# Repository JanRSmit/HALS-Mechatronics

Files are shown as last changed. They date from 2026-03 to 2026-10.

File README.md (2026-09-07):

# HALS-Mechatronics design

Note: see update status and end of this README.

THE HALS (Holographic Acoustic Loudspeaker Scanner) Mechatronics design process documentation and 3D models. 
Unlike code a physical device cannot be copied. So instead in this repository covers the design, construction, alignment and test process i followed. In this way it provides a path for others to follow and produce their own version of the HALS-Mechatronics.

HALS is composed of 3 main components:

·         Mechatronics design: This repository

·         Measurement s/w    :  [NFS](https://github.com/TomKamphuys/NFS) 

·         Postprocessing s/w  :  [lah-scanner](https://github.com/dfapinov/lah-scanner)

The september 2026 version of the HALS-Robot, almost ready to run a measurement:
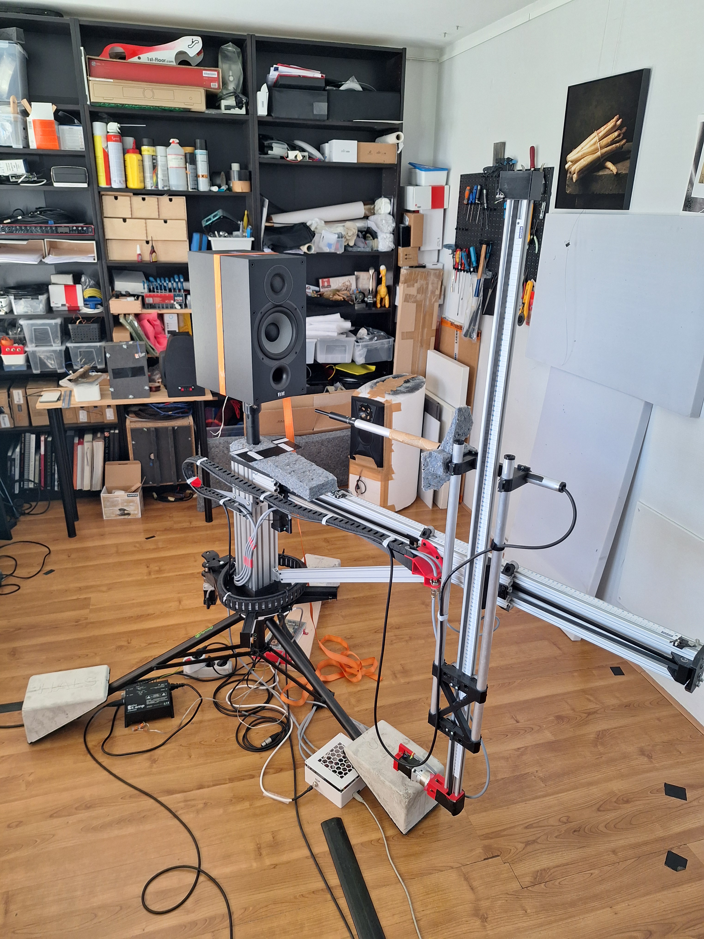
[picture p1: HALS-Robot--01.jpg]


## The start

  
The design for me started in July 2025 with a rough sketch depicting a compartimented approach. The reason being that the DIYAUDIO thread "Klippel Near Field Scanner on a Shoestring" sort of came to a silent stand-still despite Tom Kamphuys efforts.
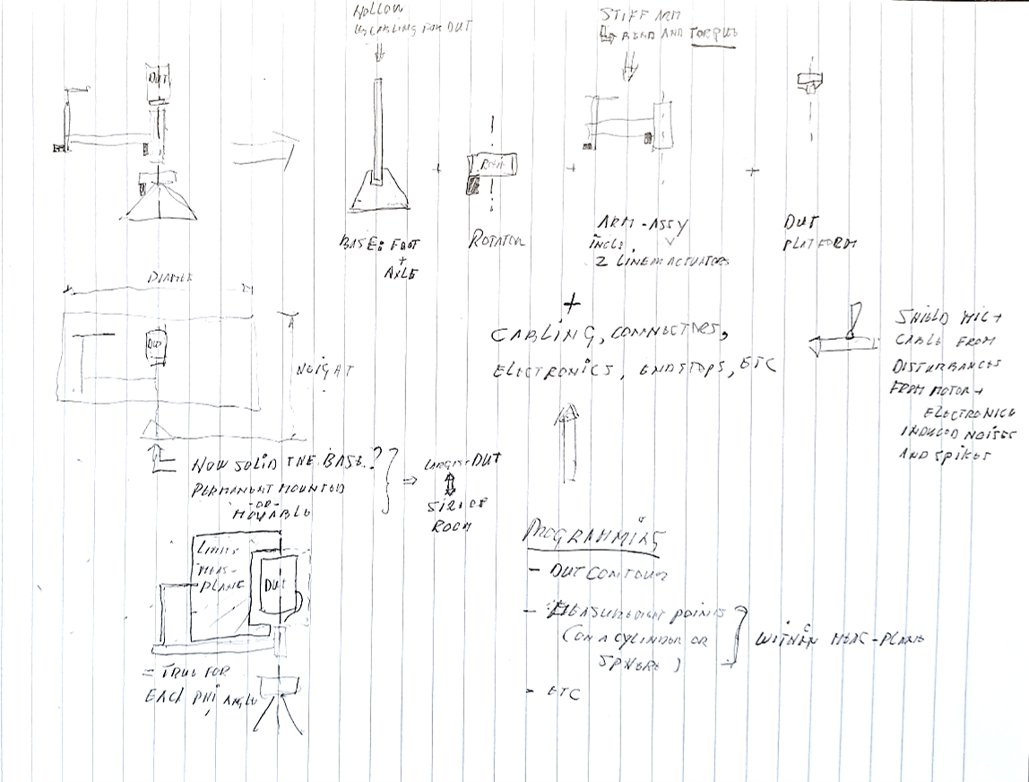
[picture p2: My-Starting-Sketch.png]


So i contacted Tom to start a collaboration where would do the mechatronics part and he the software part. A bit lateron Dimitri joined with his post-processing software.

Initially i published my approach on the thread in DIYAUDIO with an excel and pictures mostly. Recently we decided to post all on GITHUB. For me this is a learning curve ;-)

## The breakdown into compartments

My approach started as a sketch, a modular approach so it can be taken apart for movement or storage and fit in a room of 3x5x2.4m . After some desktop research in possible concepts for moving a microphone around a still standing DUT, I decided to base my solution on rotating an arm carrying the movable vertical beam for moving the mic up and down.

To do this in a reasonable period I decided, again after some intense desktop research:

\-          A sturdy steel Tripod as base and central pillar.

\-          Use of V-slot concept profiles and assemblage parts.

\-          Stepper motors & reduction gear.

\-          Internationally available , purchasable parts where possible, like bearings, axle bars, heavy quality tripod, etc.

\-          From the CNC community the grblHAL based firmware and supported controller and motor driver electronics for the motions.

\-          For the rotating movement, a timing belt HTD3M 9mm belt, and for linear movement a GT2 9mm belt.

\-          A physical construction that can be taken apart in main modules for movement to different locations or temporarily storage.

\-          Where needed 3D printable parts using PETG, actually close to 80 now, in this case Rapid PETG to reduce printing time.

### The breakdown:

\-          BASE (Foot & Main pillar):

\-          Rotating Drive:

\-          Hub-Arm-assembly:

\-          Z-axis-Mic-Assembly:

\-          STOOL: The DUT platform:

\-          Motion: Electronics, Motors & Cabling:

For each a separate folder is created containing:

\-          Decision list

\-          Pictures

\-          3D step files

\-          Assemby instruction/tutorial (still to do, preferably in an interaction with those bbuilding the device)

As an idea of the actual HALS mechatronics size:
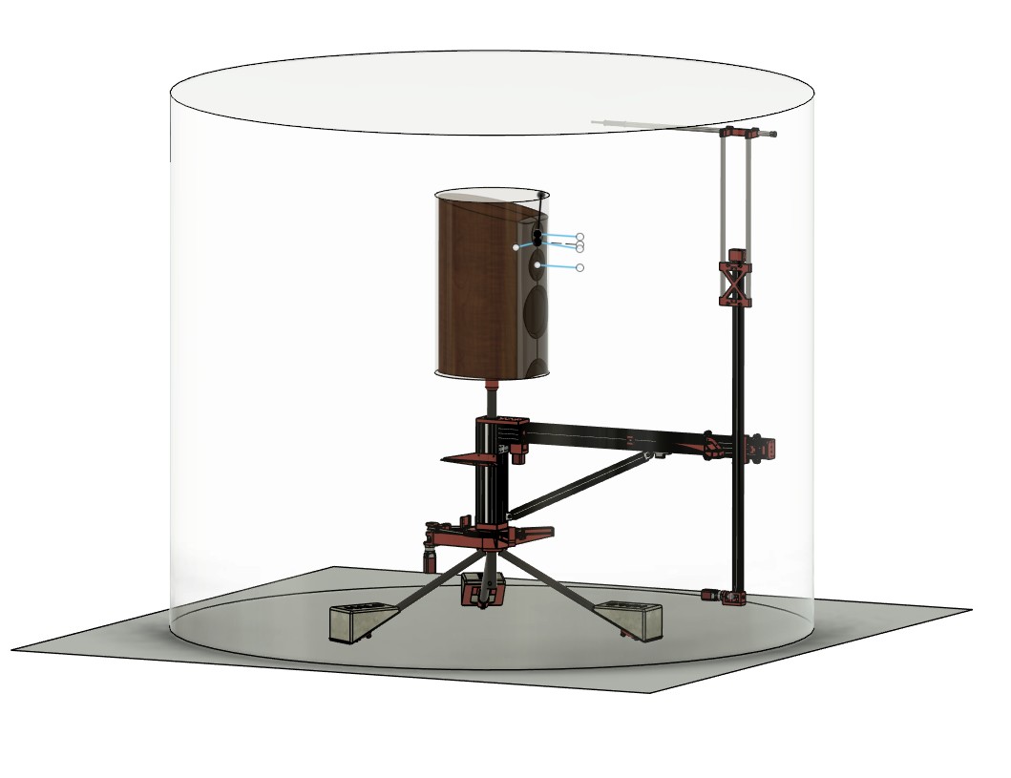
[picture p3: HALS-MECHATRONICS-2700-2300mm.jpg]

The circumscribing diameter is 2700mm, the height ~2300mm, the testobject shown is ~680mm high.

## Current Status September 2026
Now ~ 1 year later, the robot is being used for some 9 months now and still functioning fine and accurate!

Here a quite complete 3D model of the HALS robot. I just finished the models and the bills of material. Invluding fasteners, washers etc. Will do a check and then post the latest versions in tbe Github, with screencopies etc. Aim is end of this week.
The 3D is in fusion360 format. A nice feature of f360 is the isolate function, to see just one object, handy for exporting for 3D printing. Which i do in step format as the slicer i use reads step for generation of the printfile and does a better job than f360 meshing.
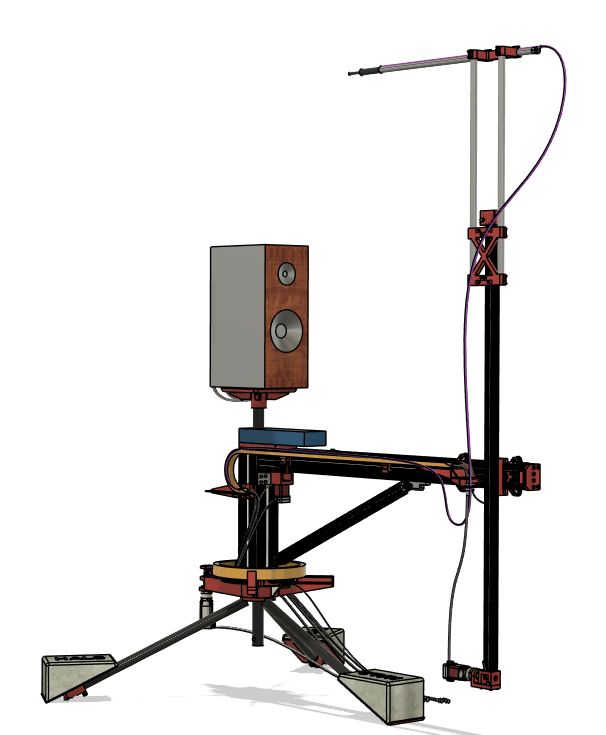
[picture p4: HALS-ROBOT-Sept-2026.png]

The controller case, powersupply for motors, and amplifier and any cabling for the DUT are not shown here.
But in reality it is like this::
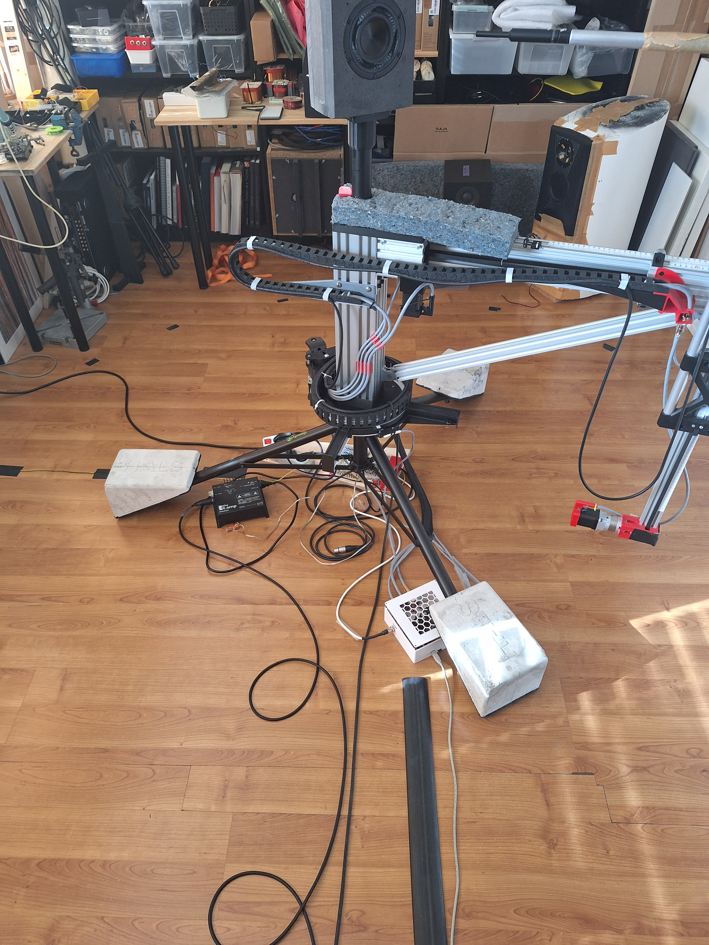
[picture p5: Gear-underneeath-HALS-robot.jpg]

The cables at bottom of picture go to the hals computer (USB) and audio i/f (XLR).

# UPLOAD STATUS
20260907: 
The 3D files, and pictures and the excel cs containing decisions and BOM are uploaded.
! What remains to be done is the explanation of how to do the squaring of the device, and some user documentation.

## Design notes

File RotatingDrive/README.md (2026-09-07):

# HALS-Mechatronics: RotatingDrive readme

The most complex module of the HALS-Mechatronics:
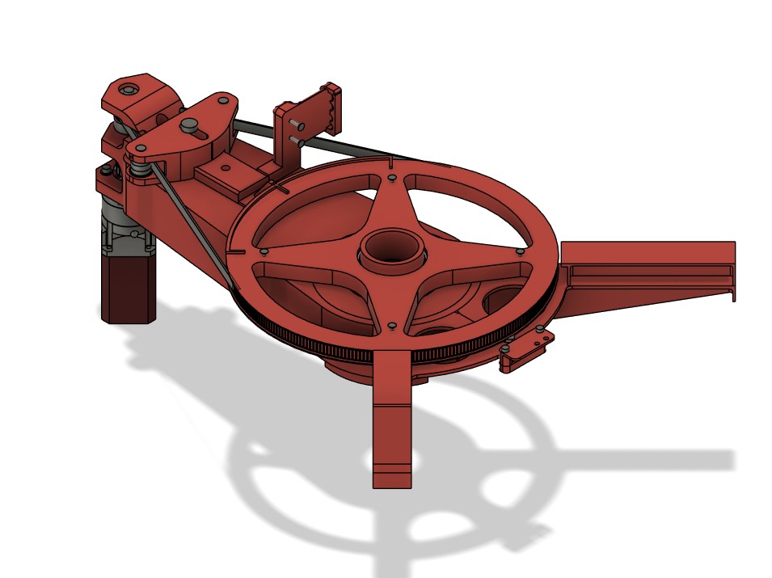
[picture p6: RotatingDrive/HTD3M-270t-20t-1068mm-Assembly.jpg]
  

Fully relying on functional 3D printing. Important here are to assure correct dimensioning of in particular holes. For the 16mm bearings i used a reamer to make these holes correct. The printing is done with Rapid PETG with layer thickness of 0.12mm and walls and top and bottom sides 2mm thick, for fill-in a minimal is used.

Both Fusion360 and Step files are present as a starting point

The excel file also includes a BOM

text

## The Gravity Tripod aluminium mounting-bracket as core mounting place
The aluminium mounting-bracket of the Gravity TSP5212LB tripod is the central piece that gives the stiffness of the tripod. Also w.r.t. torsion
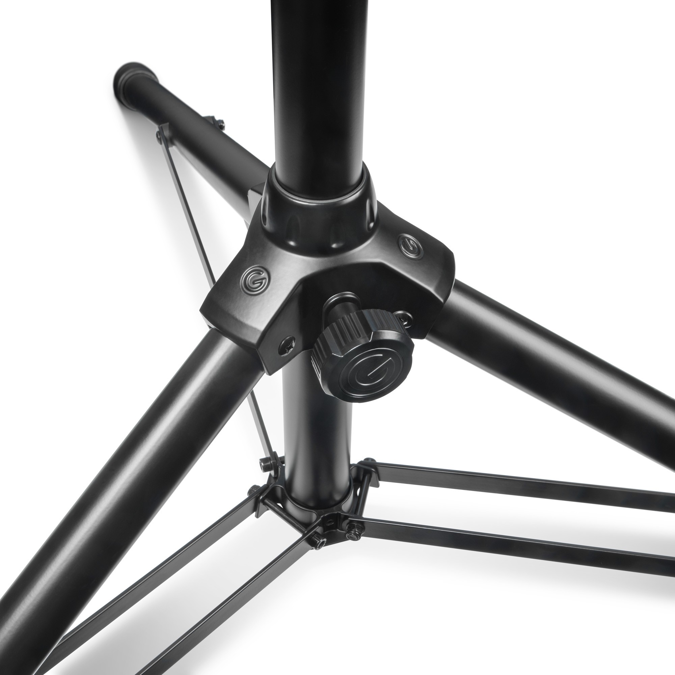
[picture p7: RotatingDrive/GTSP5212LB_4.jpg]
  
To use that for holding firmly the rotating drive i first made a 3D copy of that mounting-bracket and used that to substract it from the 3D chassis model-assembly.
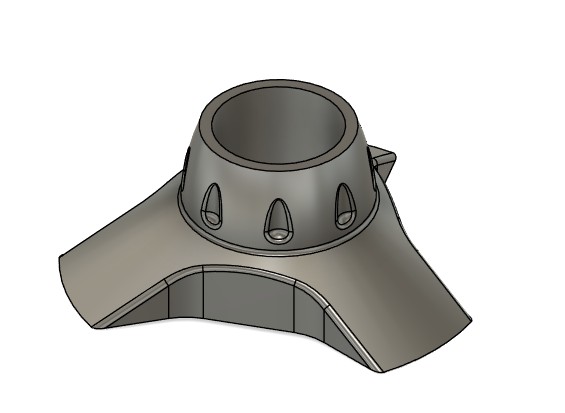
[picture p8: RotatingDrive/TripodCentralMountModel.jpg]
 

## The belt transmission
The rotating drive was the most difficult for me to determine the right motor reduction and sizing of belt etc on beforehand. Basically because i had at that time little understanding of the stepper motor behaviour.
So basically i did some off the shelf standard moment of inertia calcs, looked at the force in the belt first and availabiltiy of type of belts, and above all any usefull info regarding sizing given the use case.
Well the use-case can be best described as start-stop with also quite some accuracy. It turned out to be a oulier type of use-case. But sources from Gates and from a byonic knee study of a university i learned that pre-tensioning of the belt is crucial and should be pretty high.
To get positioning accuracy it is better to have enough steps per move, either by a reduction or microstepping. 
And GRBL , lateron grblHAL, does not have a specific function for + / - 180 degrees rotation. Luckily a rotation is a linear (1-dimensional) movement as is a straight line movement, so in GRBL specification where you enter the steps per mm movement, for the rotation that therefore is steps per 1 degee movement. 
Looking at the force a belt can handle, its availability and given the 3D modeling needed for the main pulley i settled for HTD3M-9mm toothed belt.
To test, i built a hub-arm assembly with some wooden beams, and applied several kilos of mass on it. THe Z-axis assembly can be seen as a point load and calcs show it is the most important factor in the inertia. So 3D printed a simple rotating drive concept and tested.
At that time we stil used Arduino for the controller, that is limited in its microstepping.
Still testing showed that with enough reduction a precise start-stop was possible, with appropriate accelleration setting in GRBL. But also that the forces on the chassis were considerable, thus to prevent too much deformation of chassis the outer-fibre distances and skinn thickness need to be enough to keep the load well in the linear range of the 3D FDM print material , being Rapid PETG from Elegoo. Its creep behaviour is fine.
In the second (revised) proto the reduction of 135:1 (270t-20t plus 10:1 motor reduction) gave the accuracy within 1 degree, and at enough speed  for a 180 degree move (~ 9 seconds).
The belt-tensioning mechnanism has to be in both belt-lengths given the start-stop and the forward-reverse direction of movements.
For the motor pulley one can buy that, but for the main pulley i decided for 270 teeth and with a macro easily modeled in Fusion360. Test prints showed that the quality/accuracy was fine.
The only real issue i had was the calculation of the length of the belt in combination with the centrline distances of motor and main. The calculation on the Dold-Mechatronik.de website was by far the best: https://www.dold-mechatronik.de/Zahnriemen
The way the chassis is mounted on the tripod mount-bracket proved to be a right choice. Rigid yet can be removed if needed for storage or transport.

## The 3d printed parts forming the Chassis

There is a video: Video-RotatingDrive-3Dprint-parts.mp4  that gives a view of the assembled parts forming the rotating drive chassis.

## The 3D printed 270t HTD3M pulley

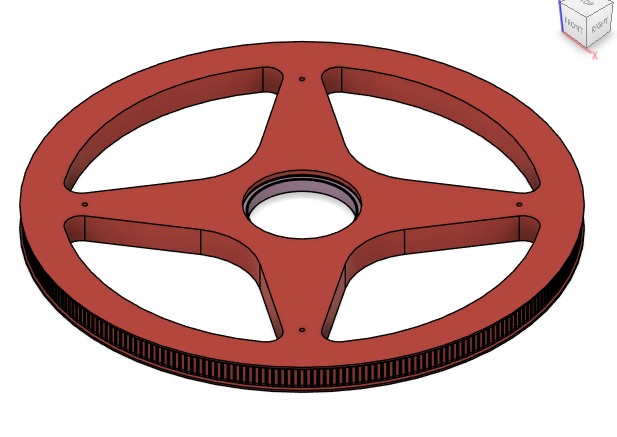
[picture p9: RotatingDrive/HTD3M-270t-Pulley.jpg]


## Images of latest version
Latest version of RotatingDrive before mounting on BASE and mounting of CableChain supports:
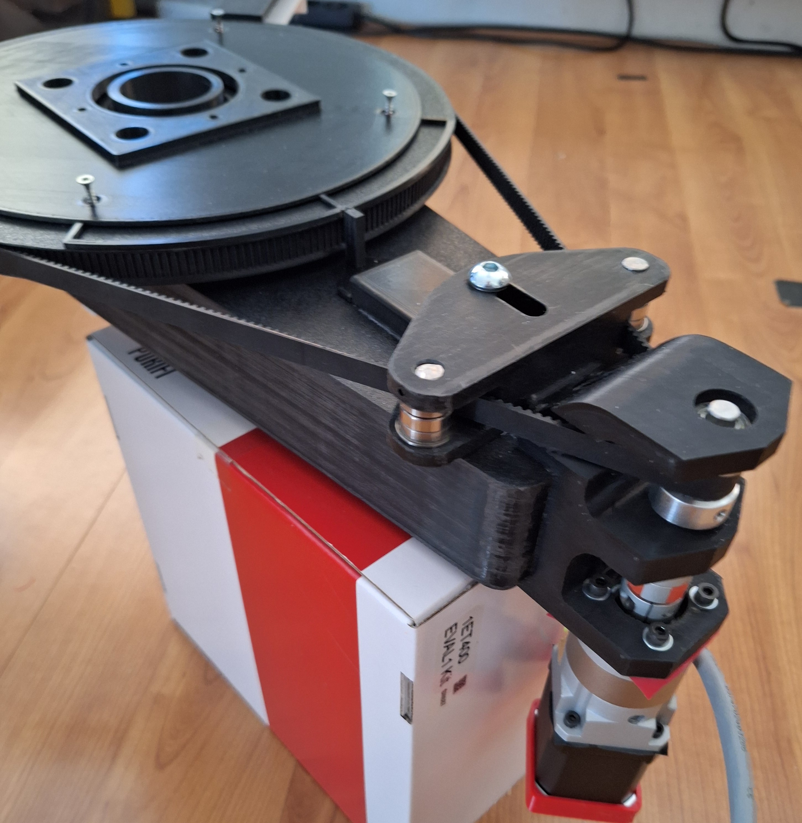
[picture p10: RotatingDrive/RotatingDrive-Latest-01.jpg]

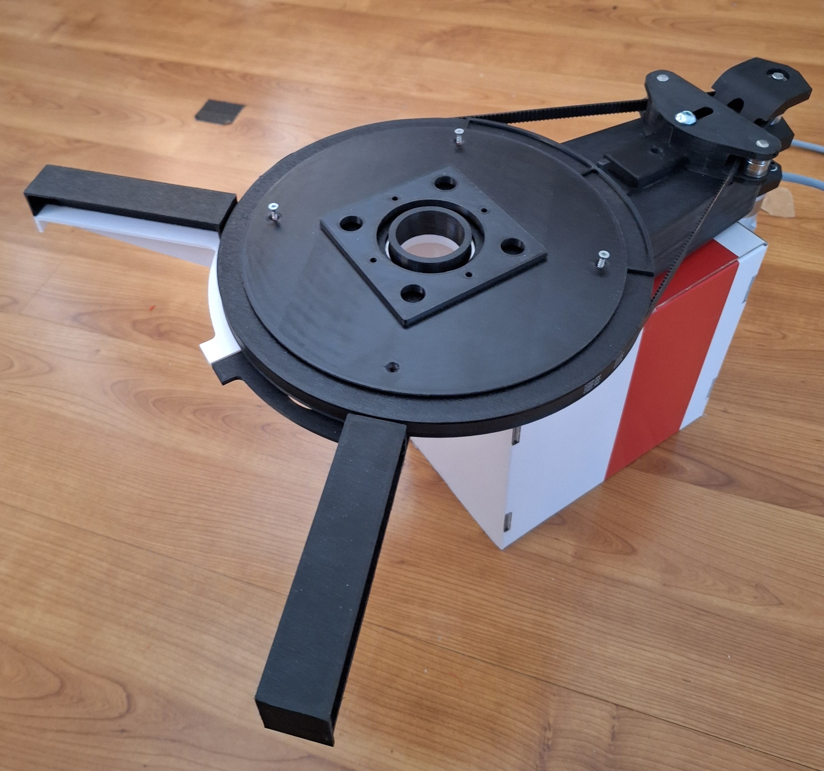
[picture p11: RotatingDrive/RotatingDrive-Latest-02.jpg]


Note: the pictures also show some parts that form a vernier scale used to measure the accuracy. These parts are optional.

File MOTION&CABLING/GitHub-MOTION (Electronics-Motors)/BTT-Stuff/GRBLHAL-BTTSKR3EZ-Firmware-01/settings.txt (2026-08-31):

%
;
; 2026-01-26T12:40
;
; grblHAL
; 1.1f.20260107
; [OPT:VNMSL,100,1024,3,0]
; [NEWOPT:ENUMS,RT+,NOPROBE,EXPR,TC,SED,TMC=7]
; [FIRMWARE:grblHAL]
; [NVS STORAGE:*FLASH 32K]
; [FREE MEMORY:204K]
; [DRIVER:STM32H723]
; [DRIVER VERSION:260109]
; [BOARD:BTT SKR-3]
; [AUX IO:5,2,0,0]
; [PLUGIN:Bootloader Entry v0.02]
; [PLUGIN:Trinamic v0.30]
;
$N0=
$N1=
; 0 - Step pulse time
$0=2.0
; 1 - Step idle delay
$1=255
; 2 - Step pulse invert
$2=0
; 3 - Step direction invert
$3=2
; 4 - Invert stepper enable output(s)
$4=7
; 5 - Invert limit inputs
$5=0
; 9 - PWM spindle options
$9=1
; 10 - Status report options
$10=511
; 11 - Junction deviation
$11=0.010
; 12 - Arc tolerance
$12=0.002
; 13 - Report in inches
$13=0
; 15 - Invert coolant outputs
$15=0
; 16 - Invert spindle signals
$16=0
; 18 - Pullup disable limit inputs
$18=0
; 20 - Soft limits enable
$20=0
; 21 - Hard limits enable
$21=1
; 22 - Homing cycle
$22=1
; 23 - Homing direction invert
$23=0
; 24 - Homing locate feed rate
$24=25.0
; 25 - Homing search seek rate
$25=750.0
; 26 - Homing switch debounce delay
$26=250
; 27 - Homing switch pull-off distance
$27=2.000
; 28 - G73 Retract distance
$28=0.100
; 29 - Pulse delay
$29=0.0
; 30 - Maximum spindle speed
$30=1000.000
; 31 - Minimum spindle speed
$31=0.000
; 32 - Mode of operation
$32=0
; 33 - Spindle PWM frequency
$33=5000
; 34 - Spindle PWM off value
$34=0.0
; 35 - Spindle PWM min value
$35=0.0
; 36 - Spindle PWM max value
$36=100.0
; 37 - Steppers to keep enabled
$37=7
; 39 - Enable legacy RT commands
$39=1
; 40 - Limit jog commands
$40=0
; 41 - Parking cycle
$41=0
; 42 - Parking axis
$42=2
; 43 - Homing passes
$43=1
; 44 - Axes homing, first phase
$44=4
; 45 - Axes homing, second phase
$45=3
; 46 - Axes homing, third phase
$46=0
; 56 - Parking pull-out distance
$56=5.0
; 57 - Parking pull-out rate
$57=100.0
; 58 - Parking target
$58=-5.0
; 59 - Parking fast rate
$59=500.0
; 60 - Restore overrides
$60=0
; 61 - Safety door options
$61=0
; 62 - Sleep enable
$62=0
; 63 - Feed hold actions
$63=3
; 64 - Force init alarm
$64=0
; 100 - X-axis travel resolution
$100=400.000
; 101 - Y-axis travel resolution
$101=80.000
; 102 - Z-axis travel resolution
$102=1200.000
; 110 - X-axis maximum rate
$110=5000.000
; 111 - Y-axis maximum rate
$111=10000.000
; 112 - Z-axis maximum rate
$112=900.000
; 120 - X-axis acceleration
$120=100.000
; 121 - Y-axis acceleration
$121=100.000
; 122 - Z-axis acceleration
$122=5.000
; 130 - X-axis maximum travel
$130=1200.000
; 131 - Y-axis maximum travel
$131=600.000
; 132 - Z-axis maximum travel
$132=360.000
; 140 - X-axis motor current
$140=1300
; 141 - Y-axis motor current
$141=1300
; 142 - Z-axis motor current
$142=1300
; 150 - X-axis microsteps
$150=16
; 151 - Y-axis microsteps
$151=16
; 152 - Z-axis microsteps
$152=16
; 200 - X-axis StallGuard2 fast threshold
$200=22
; 201 - Y-axis StallGuard2 fast threshold
$201=22
; 202 - Z-axis StallGuard2 fast threshold
$202=22
; 210 - X-axis hold current
$210=50
; 211 - Y-axis hold current
$211=50
; 212 - Z-axis hold current
$212=50
; 220 - X-axis stallGuard2 slow threshold
$220=22
; 221 - Y-axis stallGuard2 slow threshold
$221=22
; 222 - Z-axis stallGuard2 slow threshold
$222=22
; 338 - Trinamic driver
$338=7
; 339 - Sensorless homing
$339=0
; 341 - Tool change mode
$341=0
; 342 - Tool change probing distance
$342=30.0
; 343 - Tool change locate feed rate
$343=25.0
; 344 - Tool change search seek rate
$344=200.0
; 345 - Tool change probe pull-off rate
$345=200.0
; 346 - Tool change options
$346=1
; 370 - Invert I/O Port inputs
$370=0
; 372 - Invert I/O Port outputs
$372=0
; 384 - Disable G92 persistence
$384=0
; 392 - Spindle on delay
$392=4.0
; 393 - Coolant on delay
$393=1.0
; 394 - Spindle on delay
$394=0.0
; 398 - Planner buffer blocks
$398=100
; 481 - Autoreport interval
$481=0
; 485 - Keep tool number over reboot
$485=0
; 486 - Lock coordinate systems
$486=0
; 534 - Output NGC debug messages
$534=0
; 539 - Spindle off delay
$539=0.0
; 651 - Chopper toff
$651=5
; 652 - Chopper tbl
$652=1
; 654 - Chopper hstrt
$654=3
; 655 - Chopper hend
$655=5
; 657 - Chopper random TOFF
$657=0
; 659 - CoolStep semin
$659=5
; 660 - CoolStep seup
$660=0
; 661 - CoolStep semax
$661=2
; 662 - CoolStep sedn
$662=1
; 663 - CoolStep seimin
$663=0
; 673 - Coolant on delay
$673=0.0
; 676 - Reset actions
$676=15
; 680 - Stepper enable delay
$680=0
%

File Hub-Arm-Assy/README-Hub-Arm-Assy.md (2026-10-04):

The HUB-Arm-Assy is the second key main component next to the Base. Stiffness is a key criterium

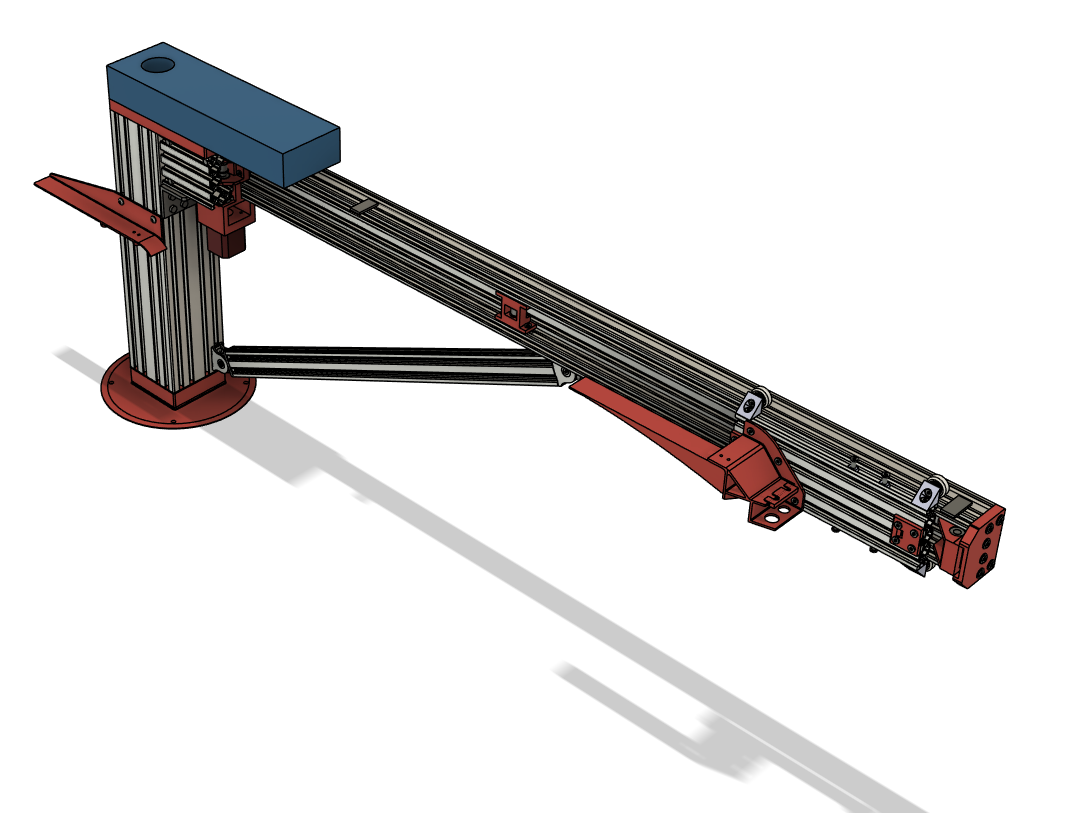
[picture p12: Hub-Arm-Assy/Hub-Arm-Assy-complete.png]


The Hub forms the central stiff part, to which the arm is connected, as well as upper and lower bearing blocks.
The gantry to move the Z-arm in and out of the DUT. 
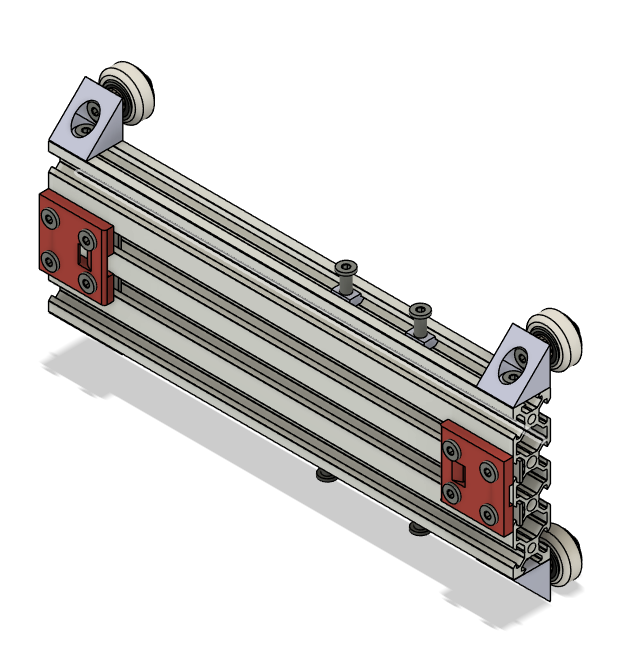
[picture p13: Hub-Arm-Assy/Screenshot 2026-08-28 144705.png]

It is part of this total assembly

The bottom bearing block has a disk shaped part attached to it, that connects with the main pulley of the rotating drive.
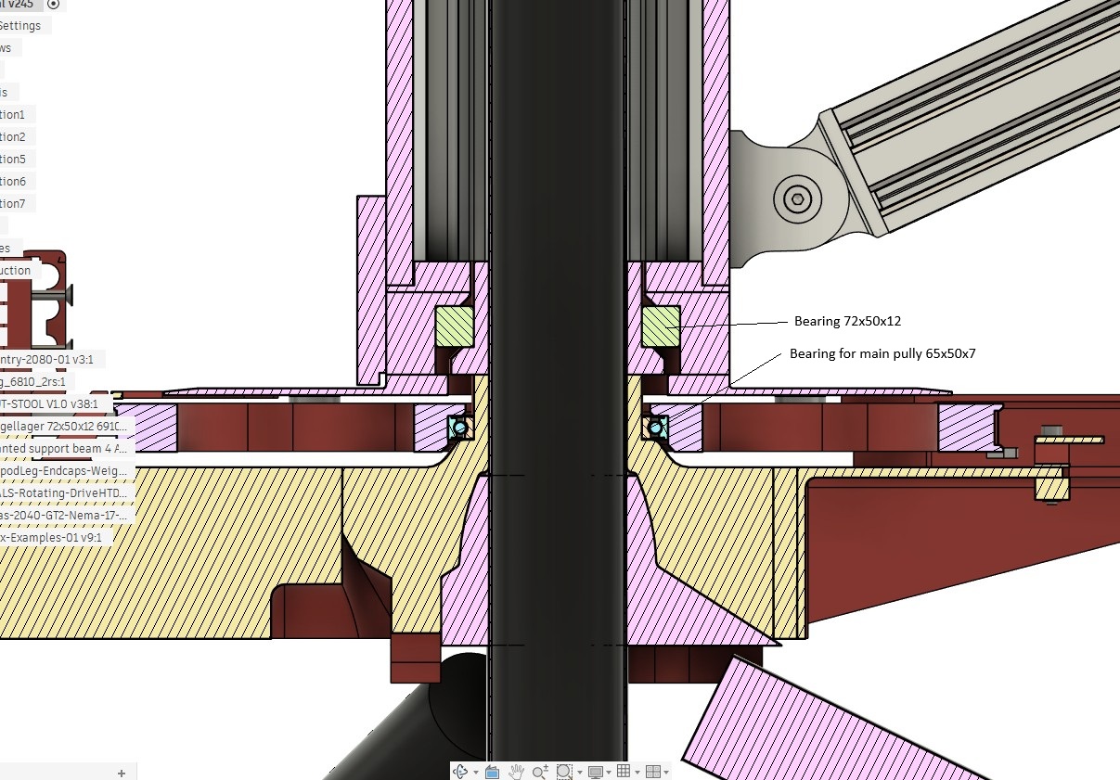
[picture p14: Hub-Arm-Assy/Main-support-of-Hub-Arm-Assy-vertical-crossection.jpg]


The mounting of arm to Hub, is combined with the mount of the Radius movement motor, again to give as much stiffness, also taking into account the 3D printed upper-bearingblock, as it also a key element in the mounting of the arm
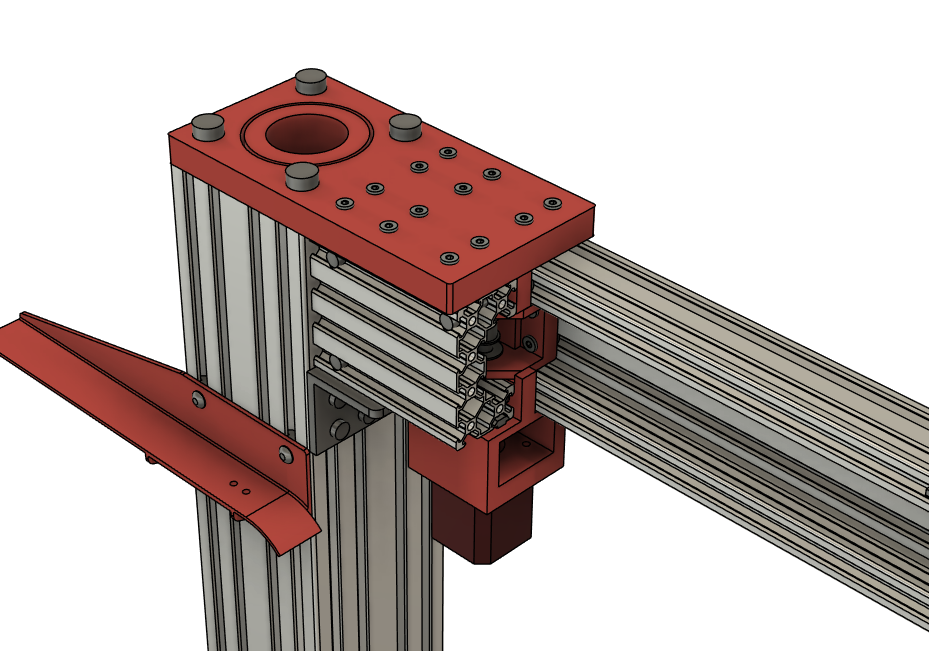
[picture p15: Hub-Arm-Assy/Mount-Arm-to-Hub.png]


A slanted support with a adjustment possibility helps in providing the needed vertical shape stiffness.
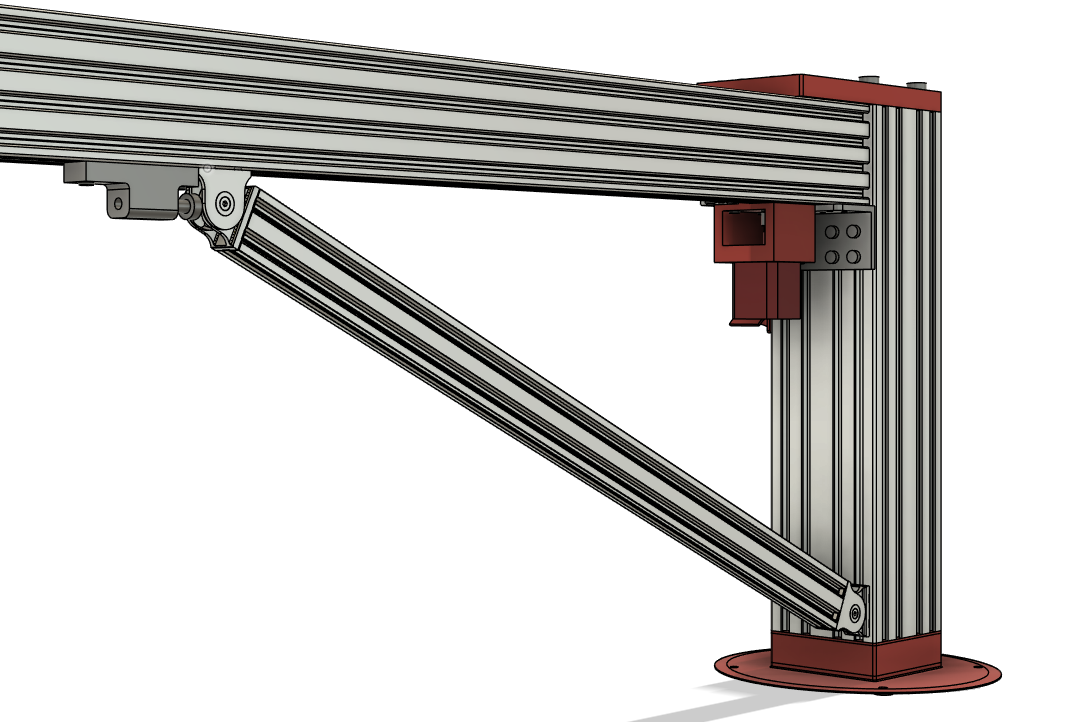
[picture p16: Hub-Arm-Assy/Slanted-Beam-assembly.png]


The Hub-Arm-assy is made such that, when dismantling the robot for transport or storage, this is a main part.

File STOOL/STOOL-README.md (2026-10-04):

# HALS-Mechatronics: STOOL readme
To place a DUT, a stool is needed. To minimize vibrations etc, the stool needs to fit tightly on the central pillar. For larger DUTS a strap is needed to secure the DUT placement, per suggestion of Mark Krachenko.
As these stools are to be 3D printed, be sure that the printer settings give a very tight fit. For strength I use Rapid PETG.
For the 3D model, a Fusion360 archive file is present for the 3D models of the stools and calibration triangle
The excel holds the decisions I made, and on a separate tab the BOM.
The images give an idea of the 3D models and the stool positioned on the central pillar.

For the calibration triangle two parts need to be printed. And when printed glued while accurately aligned.
This triangle is flexible, thus very microphone friendly, as i experienced also myself ;-)
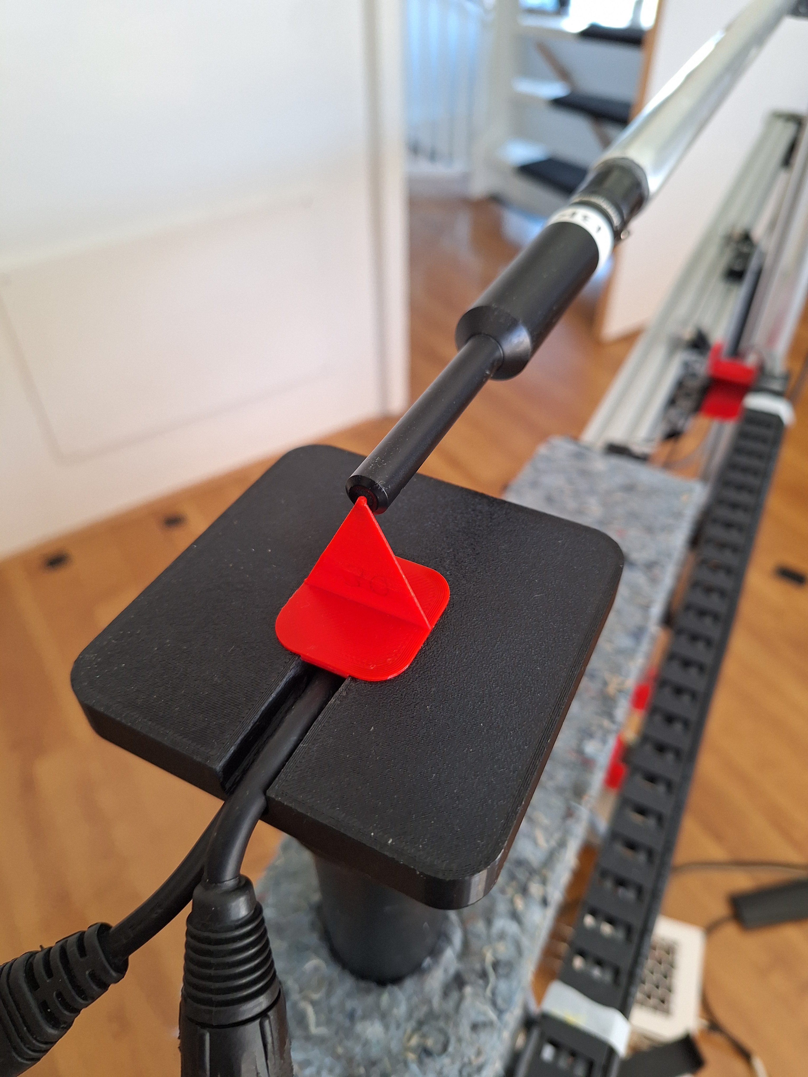
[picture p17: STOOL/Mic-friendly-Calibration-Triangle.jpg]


In the F360 file is also a first attempt to make a placement caliper, especially for small boxes. This is an area where i think some form of supporting tools are needed.

2026-10-04 DUT STool 2.0 A new design of the Stool fitting on the main beam is tested and now uploaded. It provides a myuch better tight fit.

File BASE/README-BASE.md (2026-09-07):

# HALS-Mechatronics: BASE readme
## The BASE 
Foot & Central Pillar function is fulfilled with a Gravity TSP5212B tripod, a very sturdy steel tripod. I only use the base tube of the central axis, its diameter is ~41.3mm and wall thickness of ~1.6mm. 
The extension tube is not used; it is also not very straight. This also allows me to remove the top-clamping mechanism, so to have just the bare central pillar tube.
The pictures GTSP5212LB_2 to _5 give an indication of its construction. 
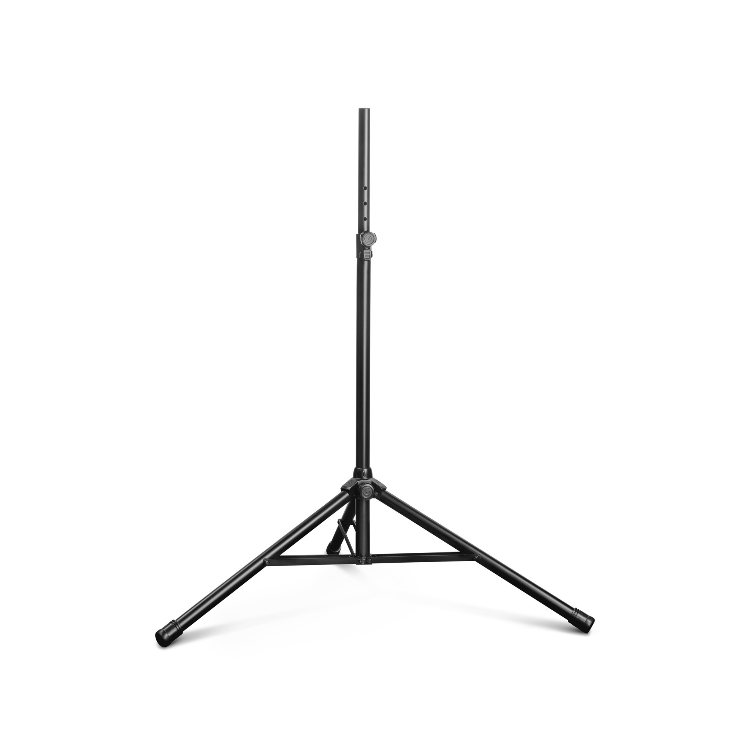
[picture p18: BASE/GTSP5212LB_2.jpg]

The aluminium mounting bracket is a crucial element:   
This will hold the rotatingdrive assembly, its details covered in RotatingDrive folder.

## Cabling for the DUT: Speaker, Mains, XLR signal
For the cabling needed for the DUT a hole is drilled in the bottom-bracket, given its design that is limited to ~ 15mm, to not weaken that part too much.
If a passive DUT, a loudspeaker cable is used, and if active a mains voltage cable and a XLR cable is used. For the XLR cable it requires desoldering and re-soldering the XLR plug.
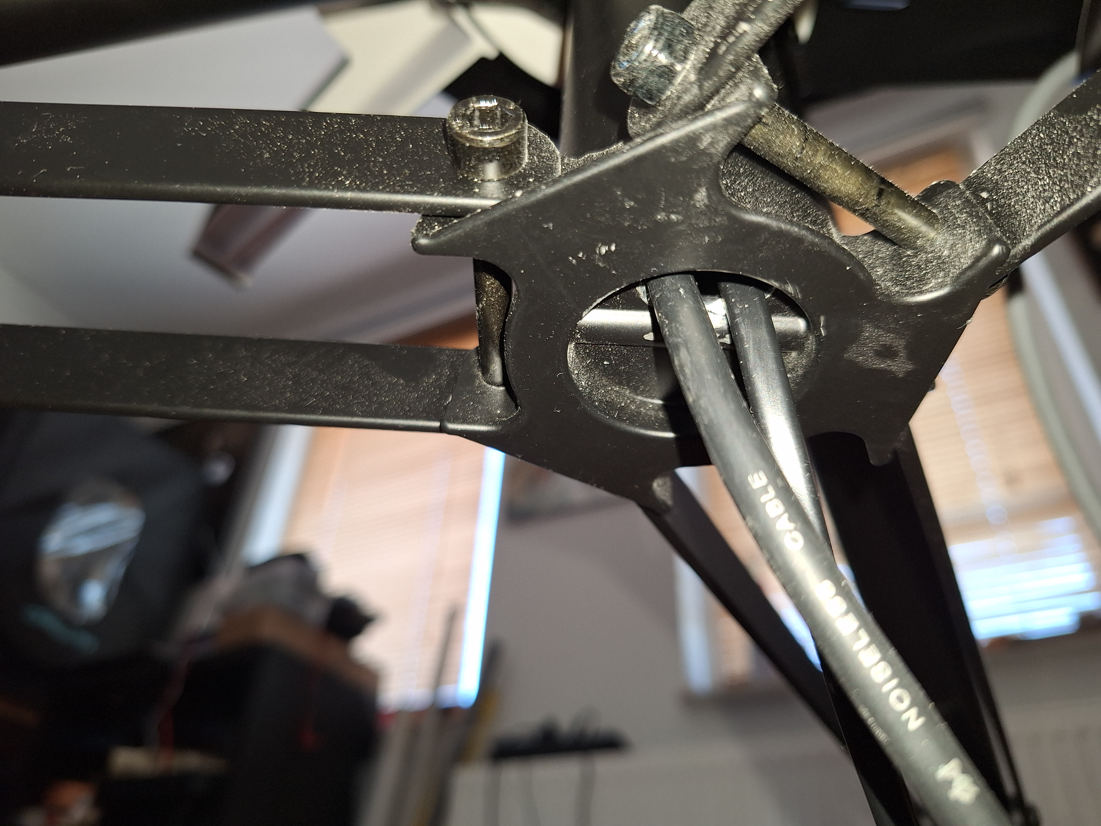
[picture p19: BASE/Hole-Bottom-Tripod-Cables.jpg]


## Stability
Testing has shown that tipping over can occur, so intially I chose to apply concrete tiles of ~7kg at the end of each leg, combined with replacing the rubber endcaps with 3D printed ones which also house level-adjustable screw.
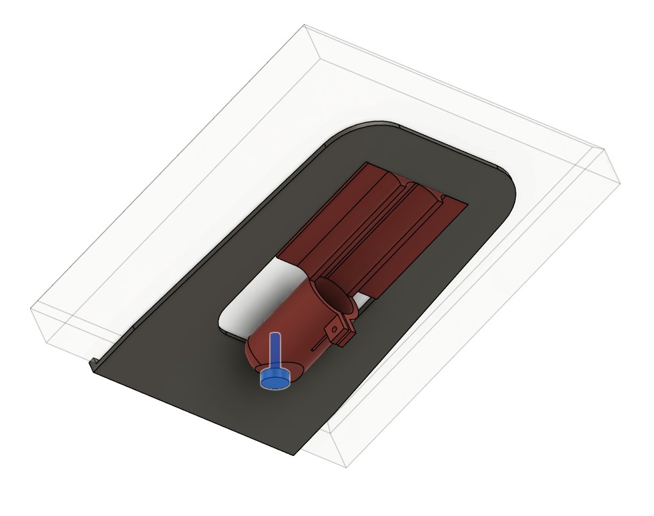
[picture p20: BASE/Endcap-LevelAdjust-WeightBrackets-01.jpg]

The tiles proved it was ok, so a more functional shape is designed and used as a mould for casting concrete:
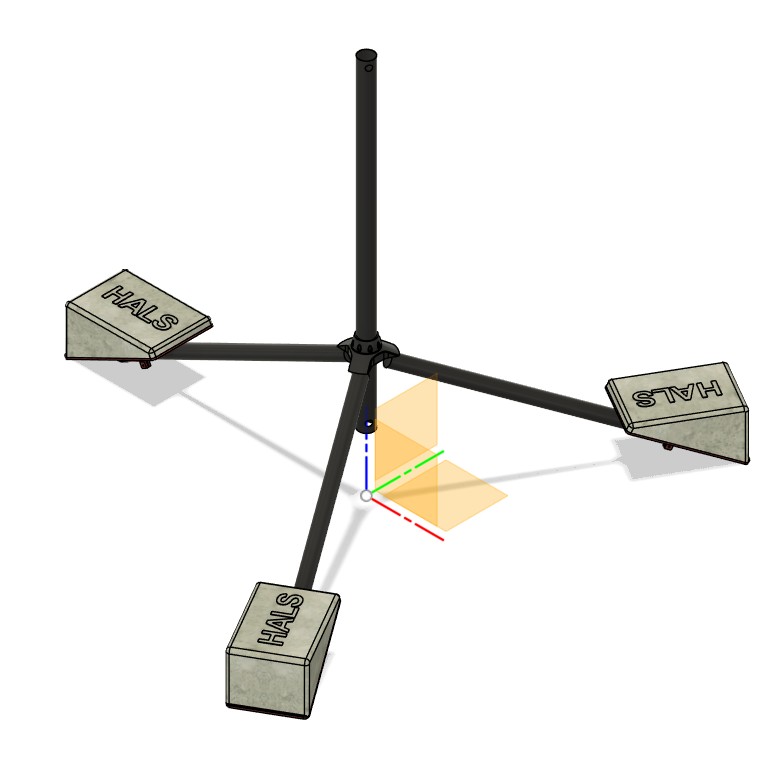
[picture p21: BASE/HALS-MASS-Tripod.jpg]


The casted concrete weight are now in use, and functions fine.

## 3D models
For the 3D models,  Fusion360 archive files -TripodLeg-Endcaps-WeightBrackets.f3z- are present for the 3D models of the endcap, mass-plateau-glued and weight-bracket (to be glued to the 7kg mass). 
The adjustable M8x24mm foot(screw) is also as simple 3D model present.
The excel holds the decisions I made, and on a separate tab the BOM.
The images give an idea of the 3D models and the used adjustable foot.
For the printable parts the Fusion360 holds the 3D models
For the casted concrete weights a compact 3D model is added, in 2 parts, to be used for casting.

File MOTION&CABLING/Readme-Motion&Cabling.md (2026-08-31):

The 'MOTION & CABLING' part of the Mechatronics is comprised of motor controller and stepper motors and is connected via USB cable to the computer running the measurement software. The motor controller is connected via shielded cabling to the motors and the end-switches. All in al a complex motion&cabling harness.

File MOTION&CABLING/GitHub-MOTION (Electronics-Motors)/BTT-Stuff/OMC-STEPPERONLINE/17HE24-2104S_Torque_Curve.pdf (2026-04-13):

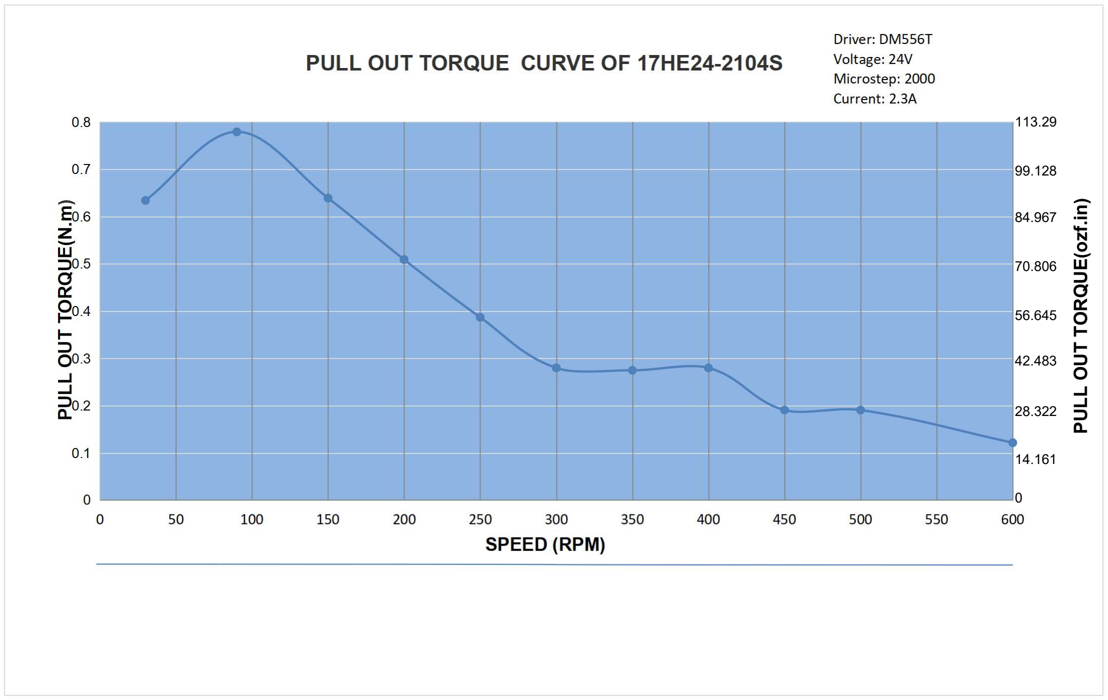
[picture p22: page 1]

113.29

99.128

84.967

70.806

56.645

42.483

28.322

14.161

# 0 PULL OUT TORQUE⁽ozf.in⁾

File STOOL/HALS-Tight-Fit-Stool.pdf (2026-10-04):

Following an idea, I created a DUT STOOL v2.0, where both in the top as at the end of the sleeve of the stool a THIGHT fit is possible. Thusfar the fit is done with a M4 screw, but that damages the central beam.

The inner diameter is after printing a very tight fit, its length increased.
At the top end I applied a taper over 15mm reducing the diameter by ~0.1mm
At the bottom end 2 M4 bolt and nut to tighten also the bottom end.
The result is a very solid mounting on the central beam of the Stool, tapping on it shows one solidness, as if it is one whole with the central beam.

DUT-STOOL 2.0: more solid fit on central beam

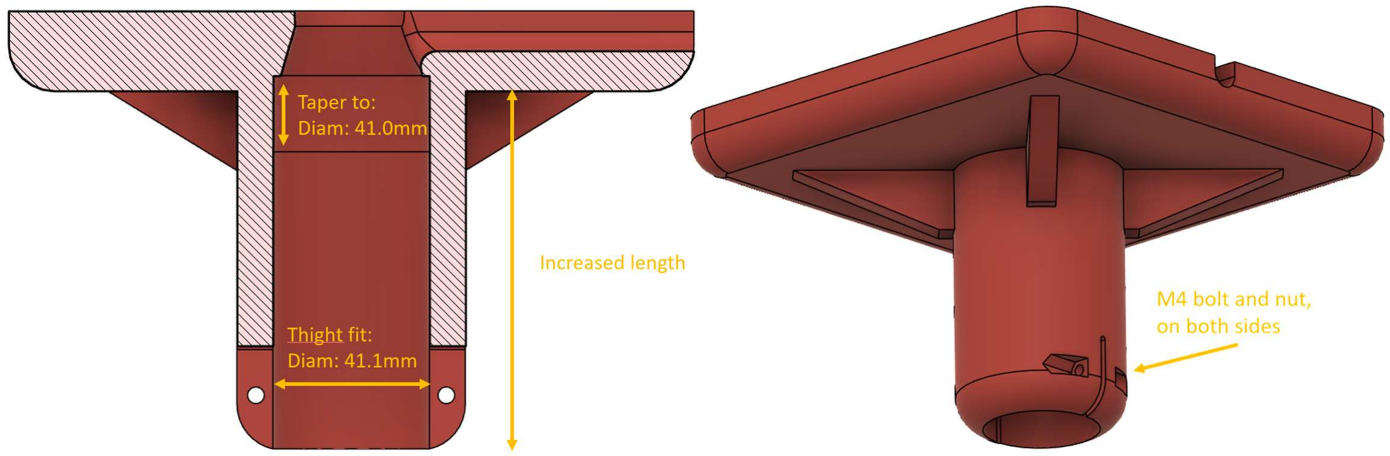
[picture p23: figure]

Crucial: Normally I remove quite quickly after printing is finished. This time I did not, I left it overnight on the printplate. Not a good idea as the shrinkage that occurs, and the stress releasing is then influenced by the plate, resulting in a not so flat top of stool, and a small mis-alignment of the sleeve that fits over the central beam.

So I printed again and removed it directly after printing. And left it on its side overnight on a table to cool and to even the stress.

The result an almost perfectly flat top, only the edges of the hole and the open conduit in the top for the cabling needed a little bit of sanding. Mounting alignment is spot-on. And the corners there is a slight droop, less than 0.1mm. Will have gaffer tape on the corners anyhow to get some friction when mounting a DUT.

DUT-STOOL 2.0: more solid fit on central beam

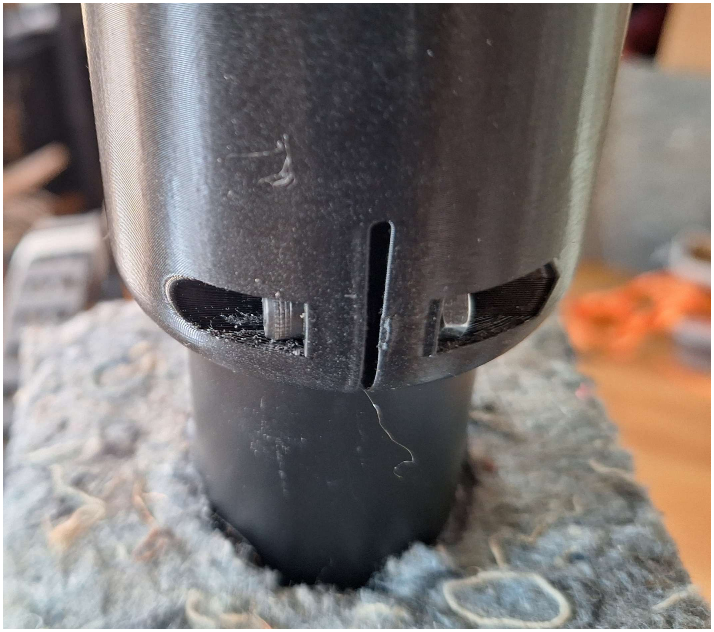
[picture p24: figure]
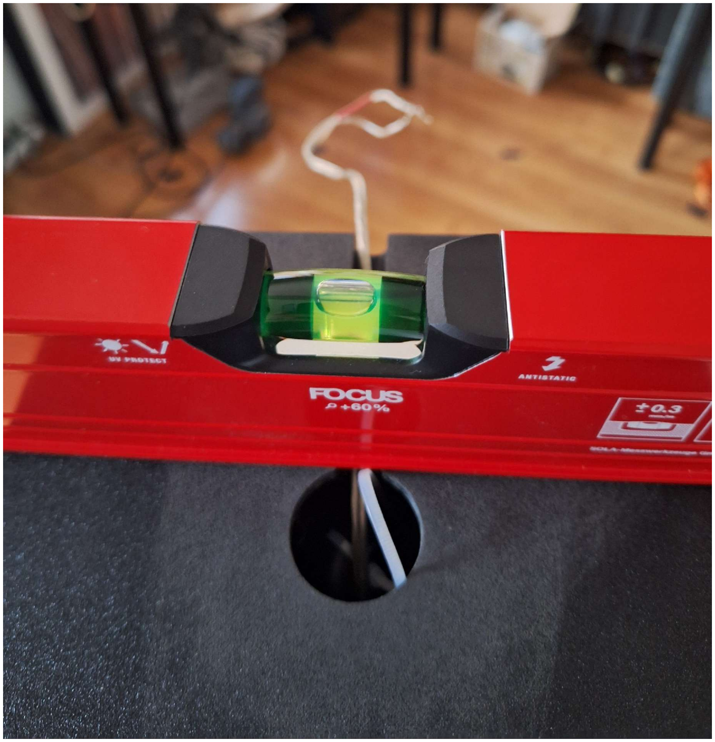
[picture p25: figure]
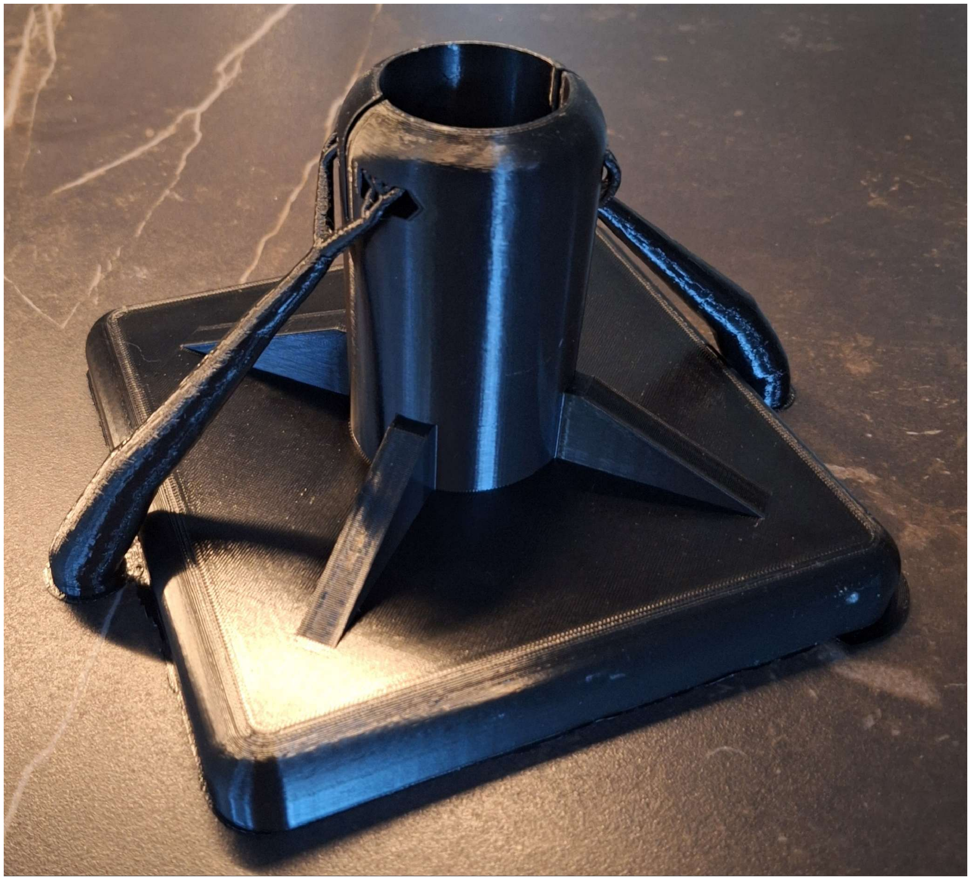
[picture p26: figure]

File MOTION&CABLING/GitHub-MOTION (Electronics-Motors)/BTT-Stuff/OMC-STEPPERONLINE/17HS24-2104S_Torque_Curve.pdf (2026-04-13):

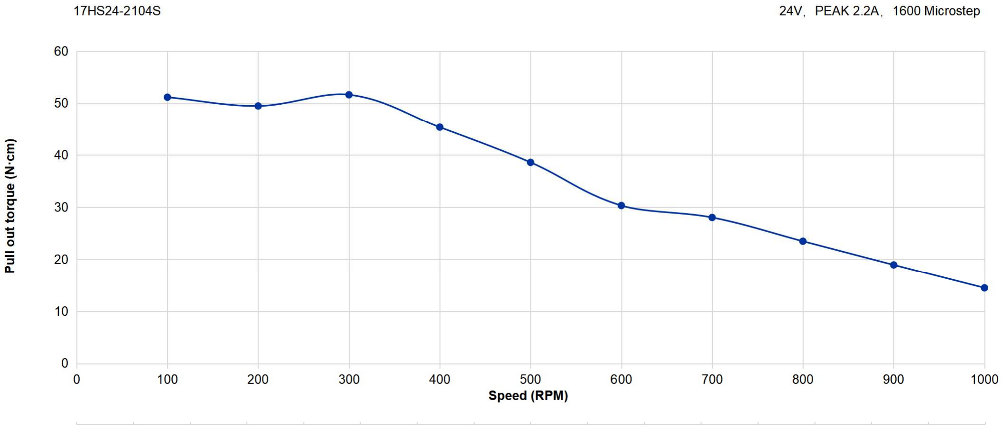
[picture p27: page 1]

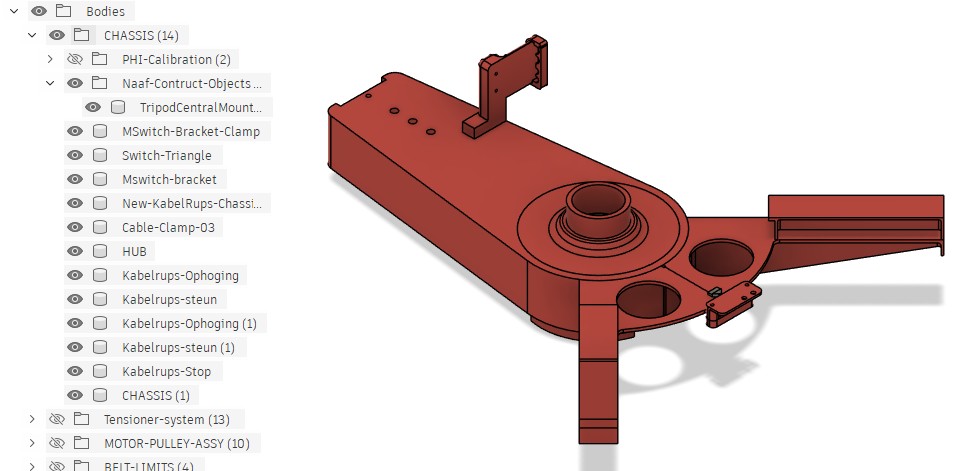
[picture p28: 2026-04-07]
RotatingDrive/CHASSIS-Assy.jpg

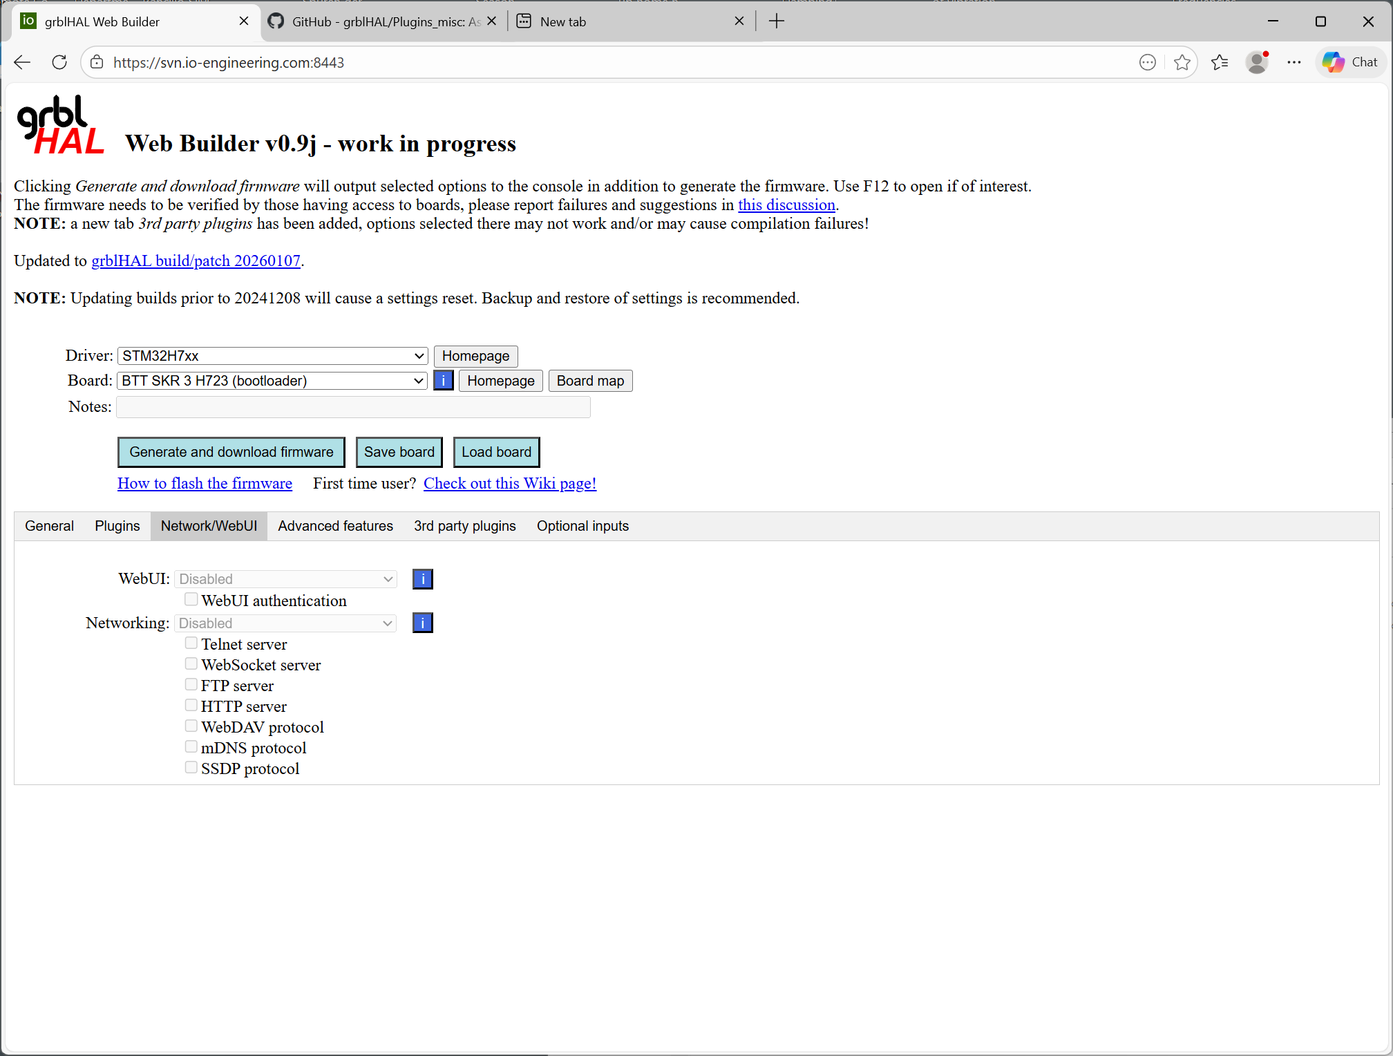
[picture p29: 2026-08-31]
MOTION&CABLING/GitHub-MOTION (Electronics-Motors)/BTT-Stuff/GRBLHAL-BTTSKR3EZ-Firmware-01/03-Screenshot 2026-01-21.png

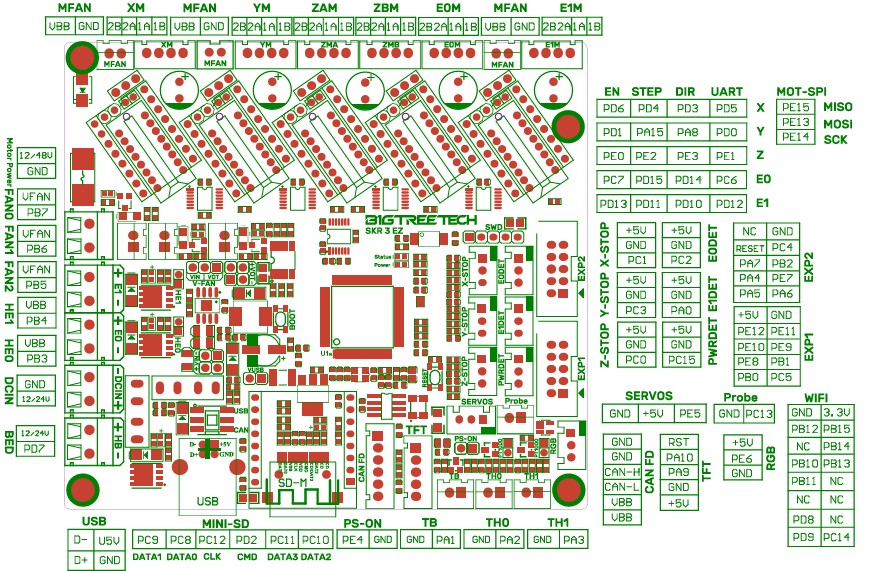
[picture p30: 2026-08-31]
MOTION&CABLING/GitHub-MOTION (Electronics-Motors)/BTT-Stuff/Hardware (SKR 3 EZ)/BTT-SKR3-EZ-PIN.jpg

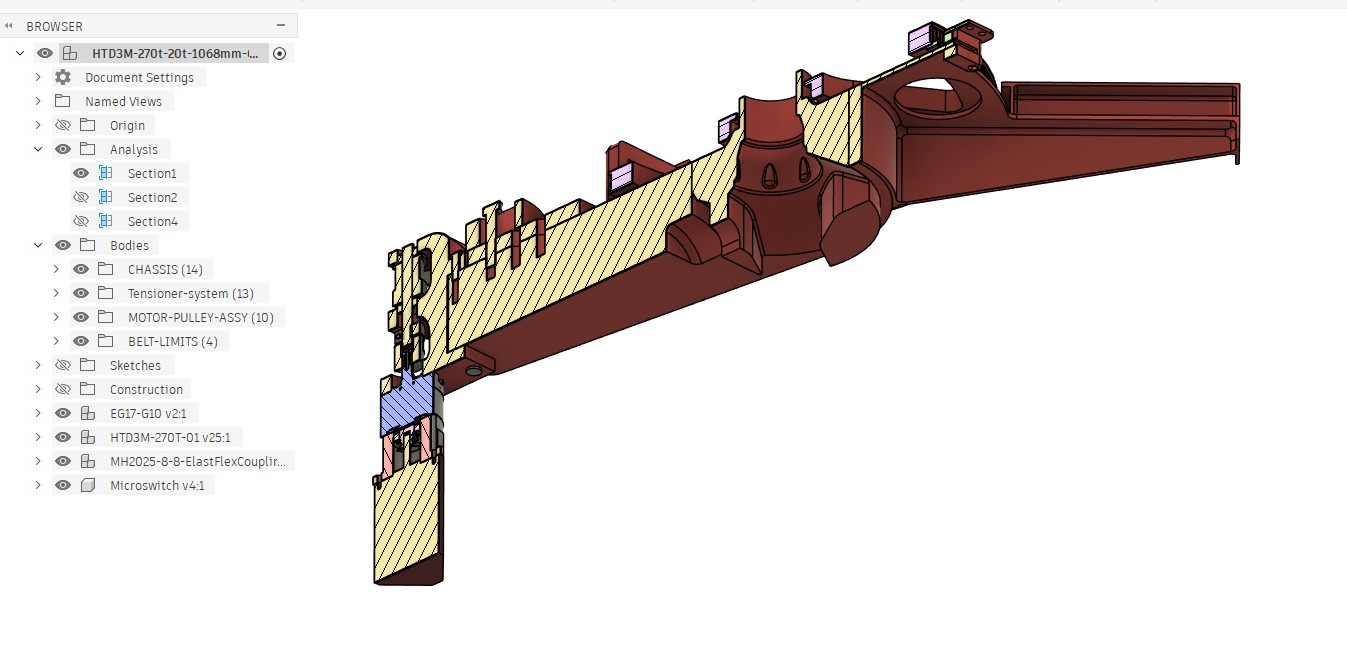
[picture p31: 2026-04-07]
RotatingDrive/CHASSIS-Assy-Cut-02.jpg

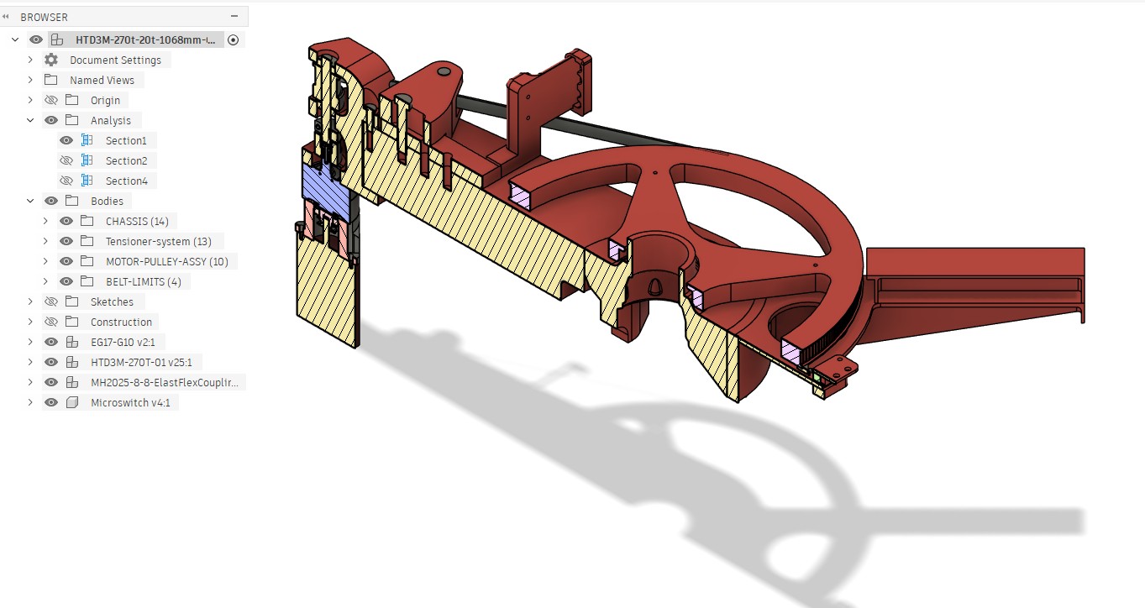
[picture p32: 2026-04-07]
RotatingDrive/CHASSIS-Assy-Cut-01.jpg

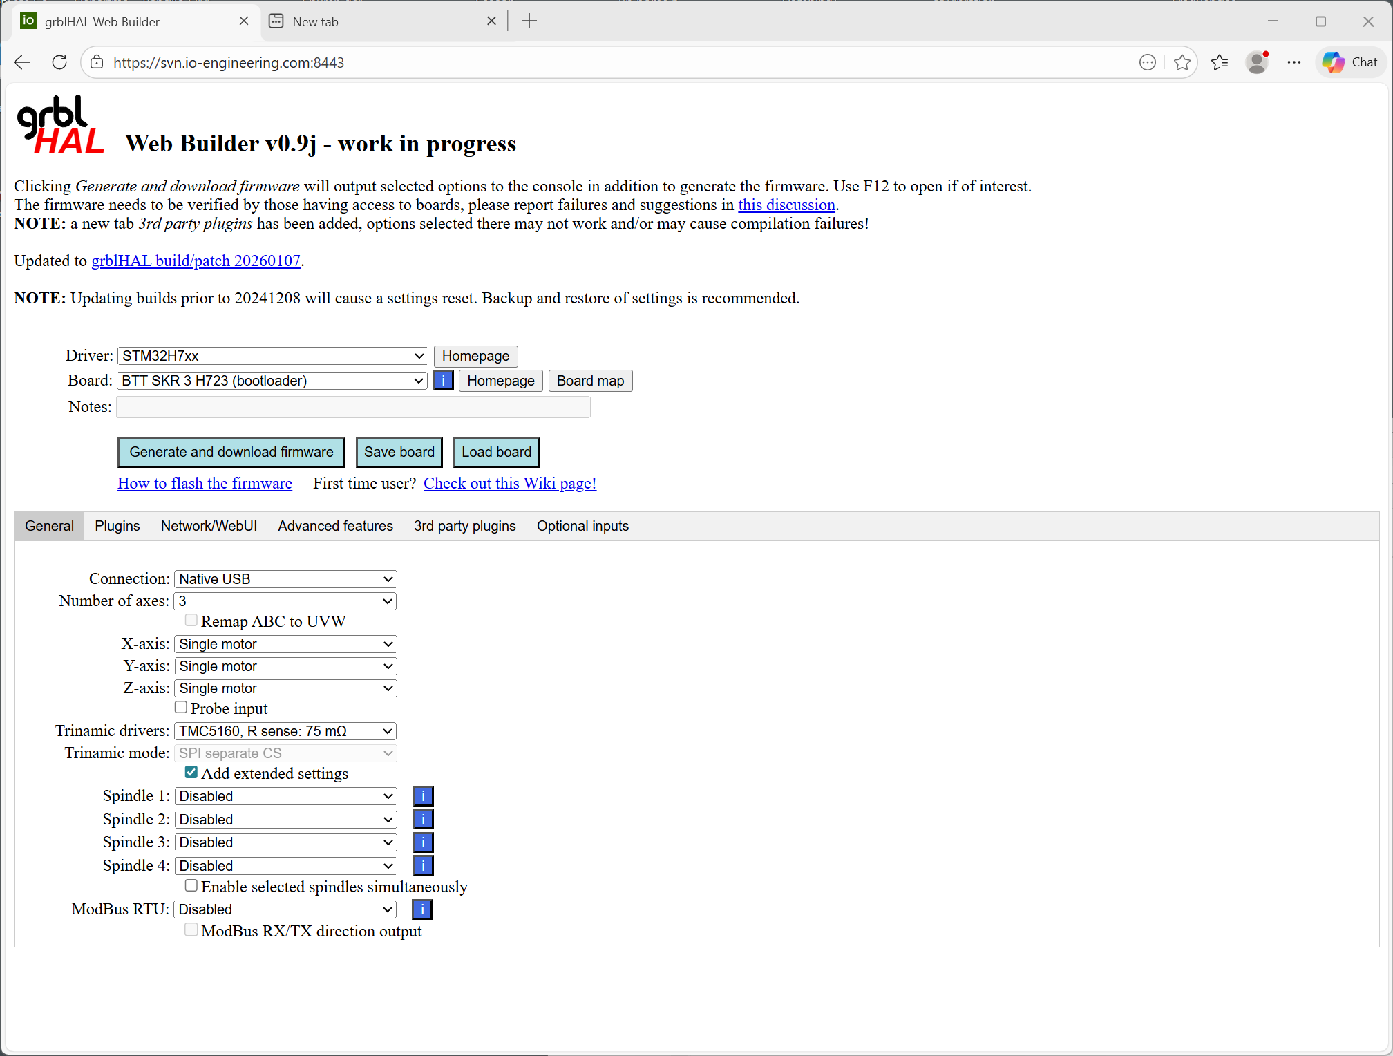
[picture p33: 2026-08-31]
MOTION&CABLING/GitHub-MOTION (Electronics-Motors)/BTT-Stuff/GRBLHAL-BTTSKR3EZ-Firmware-01/01-Screenshot 2026-01-21.png

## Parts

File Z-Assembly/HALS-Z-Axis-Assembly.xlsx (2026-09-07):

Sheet: Z-Axis-Mic-assy
# | Decisions
zm001 | For the moment i assume a linear belt driven actuator (vslot-20x40mm frame)and a gantry to which a 22x1.5mm alu pipe is connected, hopefully a Nema 17 moter will do, else a light Nema 23 motor. All in all roughly 1.5 kg. Will form a point-mass on the inertia calc for the total arm-assembly. Addendum: due to tolerances i went for 22x1mm, now the neutrik XLR plug passes through properly, see also zm005.
zm002 | Current design underway is based on v-slot 20x40mm profile (length 1500mm), 20mm side is DUT-facing to minimize reflections, the 40mm choice is for stiffness to carry the motor-drive. Addendum: I went for 1400 length, but more length is possible given the motorisation. Much more length will need a stiffer belt i presume.
zm003 | To keep the loads by moment as low as possible, the 20x40 to be mounted in the arm gantry with a 2mm insert in between leaving 2mm room for the belt to pass through. So the motor-drive can be placed in a least moment inducing position. Addendum: This is replaced by letting the belt pass through the central opening of the Vslot20x40 profile.
zm004 | The motor now is a Nema 17 sized motor, with 5mm axle, the driving pullet a GT2-20t for more torque yet not so much bending of the toothed belt. Addendum: superseded. see zm007 and zm010
zm005 | Design based on using alu tubes 22x1.5. Reduction of weight and better balance. (to be verified) Test prints of 3D print parts to assure fit with tubes and shape/dimension correctness. To Complete when alu parts arrive. Done. Addendum: Superseded, tubes now wall thickness of 1mm, to compensate tolerances, and to reduce weight.
zm006 | When assembled, attach to proto-arm (Wooden) to test drive, balance, etc. Done, helpful in decisions towards final result.
zm007 | Consider a reduction gear of 5:1 or 10:1 , a key goal the holding of position when electric power is shut off. Checklist C009 Will require redesign of motor connecting block. A 5:1 reduction gear does not drop the gantry when power is cut. And it gives more speed(feed rate).
zm008 | Profiles, assembly parts, bolts nuts, wheels etc ordered at www.systeal.com All arrived in good order.
zm009 | For 3D printing of parts with 22mm holes, I needed a correction of 0.2mm , so holes to be designed with 22.2mm, the printed size will then be ~22mm. Done
zm010 | Test with 10:1 reduction gear worked fine. The stepper is 200 steps per rotation, the reduction is 10:1, the toothed pulley is 20t, GT2 means pitch is 2mm So: 20x2=40mm per rotation of toothed pulley. Reduction is 10:1: 200x10=2000 steps per rotation of pulley. So the steps per mm is 2000/40=50 > GRBL $100=50 Indeed it moves 50mm if i jog 50mm (or send a gcode) Next the max rate (speed) , tested, and above 2000 steps are missed. At 2000 it functions, but the sound hmmm, so i settled for 1800, gives a clean whine of the motor. Returns to 0 everytime i test moving in steps etc. So pretty accurate. The acceleration settings i can play with, but at low settings (f.i. 10) the stop is a bit noisy(could be the reduction gear) or the plastic motor block. But at 100 ($120=100) it is nice and tidy. So to summarize, it works, is accurate (it returns to 0 ), its max speed is 1800mm/min or 30mm/sec. Addendum: With the use of tmc2209 stepper drivers the GRBL/Gcode settings need to be redone. The mictrosteps setting comes into play. tmc2209 by default have 1:8 microstepping active. There is a blocking limit in the Arduino Uno. This will be covered in a separate tab: GRBL-GCODE Configuration. The Arduino is replaced by GRBLHal on a BTTSKR3EZ with TMC5160 drivers, so much higher speed and microstepping available. Also a 5:1 reduction gear is applied.
zm011 | Reduced height of gantry by 40mm, is now 180mm, and its shape an X form further reducing mass. A space of ~5mm is assumed between gantry and endblocks to deal with endstop movements. The endblok for the drive and tension ends are redesigned to mount on the headsides of the 20x40vlsot bar see zm013. So total movement range is 1400-190 = 1210mm. Also the total weight/mass of the assembly is reduced by some 350gr. This includes the 22mm tubing now with wall thickness of 1mm instead of 1,5mm. Option is to replace the vertical tubes with 18x1mm tubes to save some more weight. Tested but the eigen modes are hindring, so the idea dropped.
zm012 | Endstops are now taken into account, need to be ordered. Will be mechanical switch on a tiny pcb. Checklist C011 . The position and mounting design still to do!!! Addendum, the microswitches are glued to the endblocks with some space to deal with gantry movement overshoots. The ordered endstop pcb with led etc is mounted in the Arduino controller box. So when the led is on, the connection is ok, being normally closed. Addendum: With the switch to the BTT SKR3 EZ, the endstop PCB's are dropped as the board is by default configured for NC.
zm013 | The endblocks are now bolted on the Vslot20x40 profile by 2 bolts straight on the head-end of the profile bar. Requires threading those holes in the profile. It maximizes the movement range of the gantry, and it provides a more stable positioning of the blocks, thus the alignment of the axles with the pulleys. There are always tolerances to deal with ;-)
zm014 | The tensioning endblock holds a pulley bracket that is adjustable with 2 bolts each on either side of the Vslot. Thus also allow alignment of the pulley axis to keep the belt more or less on the middle of the pulley.
zm015 | The motor enblock will be mirrored to put the motor plus reductiongear pointing to the outside. This allows the whole assy to move closer to the PHI-axis without touching the 6 legs. Addendum: for the test at Tom's place the non-mirrored endblock is used. So the motor+reduction now faces inwards. This is now the chosen configuration.
zm016 | The mic-assy with the tubes allow for some alignment of the microphone to be exactly pointing at 'zero'. To be checked at each measurement setup procedure. But when bolted tight it is very firm.
zm017 | The pictures to be updated with latest config, including impact of range by endstops.
zm018 | As an option: Replace the vertical tubes with a 18mm tube, And possibly mounted in the 22mm space with soft leather layers to provide a vibration absorption. For now decided not to do as the tube stiffness turns out to be too low..
zm019 | For the cabling on the Z-axis-Mic-assy, see the tab CSC: Cabling-Sizing-Config.
zm020 | A calibration triangle made. This to calibrate the mic to the PHI-axis. The point is 30mm above the stool top and exactly on the PHI-axis.
zm021 | There are some resonances in the Z-axis, need to address together with Tom and the controller to use, as the step frequency is the primary cause. See checklist C021. Addendum: With the deployement of a 5:1 reduction, the motor induced vibrations are well above the eigen modes of the v-slot2040 or the belt. This solves the issue
zm022 | Microswitches for the Endstops are mounted on the endblocks. And cabling with a GX12-2 connector made and mounted.
zm023 | Motor cabling made with GX16-4 connectors and added.
zm024 | On the gantry a cabling junction box is added (3Dprint). The Z-axis needs to be removable for transport or storage. See also tab CSC for more details on the cabling.
zm025 | Vibration tansmission from motorblock to frame can be blocked by thin (0.25mm, 0.50mm) elastic rubber sheets in joints. Done, It reduces the transmission. A gluestick to 'stick' the rubber to the motor helps in the assembly.
zm026 | see Checklist C033 The X-Gantry needs to be stronger at the 3mm bolt parts, one cracked . Done

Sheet: BOM-Z-Axis-Assy
BOM for the Z-Axis-Assembly |  | Naming as in F360 assembly file
Module | Part ID | Description | Quantity | Buy/Make | Notes
Motor-Kant | ZA-MK001 | Motorblok-alt-EG17-2a | 1 | Make | 3D printed, using PETG (Rapid PETG), 16mm holes for bearings best if reamed.
Motor-Kant | ZA-MK002 | Motorblok-alt-EG17-2b | 2 | Make | 3D printed, using PETG (Rapid PETG),together with 2a forms the main motor drive chassis
Motor-Kant | ZA-MK003 | M4x15 Allen screw | 4 | Buy | To mount the reduction gear to the chassis
Motor-Kant | ZA-MK004 | Allen-FlatHead-M5x20 | 6 | Buy | To assemble the chassis parts 2a and 2b, and to mount the chassis to the v-slot4020 beam
Motor-Kant | ZA-MK005 | Washer M5 | 4 | Buy | To assemble the chassis parts 2a and 2b
Motor-Kant | ZA-MK006 | Rubber shim 0.25mm thick | 2 | Make | To reduce vribration transmission (a bit)
Motor-Kant | ZA-MK007 | GT2-9mm open end belt ~ 3m | 1 | Buy | Typically sold by 5 or 10m, I purchased a 10m roll as it is also used in the Arm
Motor-Kant | ZA-MK008 | motors covered in separate assy | n.a. | n.a. | n.a.
Motor-Kant | ZA-MK009 | MH2025-8-8-ElastFlexCoupling v1 | 1 | Buy | for 8mm axles on both sides!
Motor-Kant | ZA-MK010 | Axle 8mm H7 58mm | 1 | Buy
Motor-Kant | ZA-MK011 | Flenslager-8x16x5mm | 2 | Buy
Motor-Kant | ZA-MK012 | GT2-9-20t-8mm-Pulley | 1 | Buy
Spanner-Kant | ZA-SK001 | Axle H7-8 x 38mm (1) | 1 | Buy
Spanner-Kant | ZA-SK002 | SPANNERKANT-ROMP | 1 | Make | 3D printed, using PETG (Rapid PETG)
Spanner-Kant | ZA-SK003 | GT2-9-20t-8mm-Pulley | 1 | Buy
Spanner-Kant | ZA-SK004 | Bus11x9-8mm | 1 | Make | 3D printed, using PETG (Rapid PETG)
Spanner-Kant | ZA-SK005 | Flenslager-8x16x5mm | 2 | Buy
Spanner-Kant | ZA-SK006 | M5x20-Allen-Flathead (1) | 4 | Buy
Spanner-Kant | ZA-SK007 | M5-Nut-Selfblocking | 2 | Buy
Spanner-Kant | ZA-SK008 | SPANNERKANT-STELBLOK | 1 | Make | 3D printed, using PETG (Rapid PETG), 16mm holes for bearings best if reamed.
GANTRY-Montage | ZA-GM001 | Z-As-mount-Gantry-20x80mm | 1 | Make | 3D printed, using PETG (Rapid PETG)
GANTRY-Montage | ZA-GM002 | Kabelloop-01-TPU95 | 2 | Make | Printed with TPU-95, glued with cyanoacrylate to Z-Mount, helps guiding end-switch cabling
GANTRY-Montage | ZA-GM003 | Z-Axis-Square-Shim-1mm | 1 | Make | 3D printed, using PETG (Rapid PETG), thickness depend on you construction of arm assembly.
GANTRY-Montage | ZA-GM004 | Low Profile Screw M5x10 | 4 | Buy | Also called Allen flathead. A normal Allen cylindrical head is also ok in this position
GANTRY-Montage | ZA-GM005 | ECR-MA-P6-5 | 4 | Buy | M5 Nut that fits the modul 6 slot in V-slot beams
X-GANTRY-18mm-22mm | ZA-XG001 | GANTRY-X-22mm-V01 | 1 | Make | 3D printed, using PETG (Rapid PETG)
X-GANTRY-18mm-22mm | ZA-XG002 | Klem-GT2-9mm-X | 2 | Make | 3D printed, using PETG (Rapid PETG)
X-GANTRY-18mm-22mm | ZA-XG003 | Buis-740x22x1.0mm | 3 | Buy | alu tube
X-GANTRY-18mm-22mm | ZA-XG004 | MIC-Bracket-X-22mm | 1 | Make | 3D printed, using PETG (Rapid PETG)
X-GANTRY-18mm-22mm | ZA-XG005 | GANTRY-SPACER-Block | 2 | Buy | lu block to mount v-slot wheels (systeal.com)
X-GANTRY-18mm-22mm | ZA-XG006 | Tule-22x1.0-V01 | 1 | Make | Printed with TPU-95, to guide mic-cable through the end of the mic-tube without damaging
X-GANTRY-18mm-22mm | ZA-XG007 | Allen-M3x12 | 14 | Buy
X-GANTRY-18mm-22mm | ZA-XG008 | Washer-M3 | 14 | Buy
X-GANTRY-18mm-22mm | ZA-XG009 | Nut-Me3-Hexagon | 14 | Buy
X-GANTRY-18mm-22mm | ZA-XG010 | Allen-FlatHead-M5x25 | 4 | Buy
X-GANTRY-18mm-22mm-Vslot-Wheel-assy | ZA-XGW001 | Wheel | 4 | Buy | These are typically sold as a complete set. I use the hardest wheel available at systeal.com
X-GANTRY-18mm-22mm-Vslot-Wheel-assy | ZA-XGW002 | Low Profile Screw M5 x 35 | 4 | Buy
X-GANTRY-18mm-22mm-Vslot-Wheel-assy | ZA-XGW003 | Ball Bearing 5 x 16 x 5 | 8 | Buy
X-GANTRY-18mm-22mm-Vslot-Wheel-assy | ZA-XGW004 | Solid V Wheel_Eccentric-10mm | 4 | Buy | for 10mm tool to rotate, each wheel has it own excenter to adjust not only play but also alignment with beam
X-GANTRY-18mm-22mm-Vslot-Wheel-assy | ZA-XGW005 | M5-Hex-Nut-Locking | 4 | Buy
Z-Beam | ZA-BM001 | V-slot-20x40 1400mm | 1 | Buy | At both ends two M5 threads to be cut in the appropriate hole

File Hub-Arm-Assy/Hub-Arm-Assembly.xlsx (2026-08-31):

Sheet: Hub-Arm-Assy
# | Decisions
AA001 | A torsional and bending stiff central hub that fits over the main pillar (41.5mm) and provides a good way to fix the bearing blocks, such that the whole is stiff. Also allows a stiff assembly of the arm to the hub. Result is a Alu profile of 100x100mm and 425mm long with slots for mounting the arm. Is indeed very stiff in bending and torsion.
AA002 | For the bearings I have chosen for deep-groove ball bearings with inner diameter of 50mm, and to 3D-print the bearing block and its hub so it fits somewhat tight over the main pillar. The lower bearing (6910 2RS - (50x72x12)) can handle a static force of over 1000kg. The upper bearing (6810 2RS - (50x65x7) can handle over 500kg static.
AA003 | The arm is a V-Slot C-beam 40x80mm, given its bending and torsional stiffness and still not too much weight (2 kg per meter). The length will be 1200mm, so 2.4kg. Simple stating bending check shows that the end moves less than 1mm under bending. See also AA013, a diagonal bracket added reducing the bending to negligable values.
AA004 | The brackets for mounting the arm stiff to the hub will be brackets as shown in the image. So physically stiff and robust. To be finalised when the linear actuator motor drive is designed. The current design is as depicted.
AA005 | The gantry for the Z-axis-assy, to position the 4 vslot wheels as wide as possible to reduce the effective forces on them as result of torsional loads. A vslot profile of 20x80 250mm long (0.2kg) plus wheels brackets bolts nuts rings, assumption total some 0.4kg. Checklist C005. Done
AA006 | The linear actuator for the arm, motor-drive, tensioning end, will be GT2 belt 9mm based. Checklist C005. Done.
AA007 | The arm to move to top of hub. A big angular bracket at bottomside of arm. Means redesign of arm to hub connection. And also a support beam is added to further enhance the stiffness in vertical plane.
AA008 | The 3D printable parts for the R-axis linear actuator are designed. The belt is not straight anymore, but under angles to improve the tensioning. Including a belt support halfway in the arm. The adjustable belt tensioner is part of the gantry.
AA009 | For the cable management, the part where the cabling from the rotating part is passed on to the static foot, a cable chain is required that allows rotation of at least 180 degrees in both directions. This amounts to a cable chain of ~1.0m
AA010 | For the linear actuator drive I chose a 9mm GT2 belt, a 20t motor pulley, a guide pulley about 60% of the return side, and at the arm-end the tensioning. For the tensioning I use a pulley bracket that is adjustable with 2 bolts, so I can also align the pulley axis to keep the belt more or less in the middle of the pulley. The pulley bracket is made to allow a small rotation in vertical plane.
AA011 | The belt mounting bracket for mounting on the gantry is outcome of an iteration, this version is very stable and easy to mount. Also checked the internet for lessons learned, this version is in line with those lessons. Crucial is that the belt is normal to the end of the gantry, else it will give a belt mis-alignment at the motor and tensioner pulley's.
AA012 | The upper bearing is fully 3D printed, no custom aluminium plate in use. It works. In a next working version it will be slightly adjusted so it can be bolted with shoulder-screws to the Aluminium profile, should give a slightly stiffer mount. > Checklist C015
AA013 | To increase the total stiffness in vertical plane, a bracket is added (vslot20x40 profile). And an adjustment bolt also to adjust the angle of he arm relative to the hub.
AA014 | The Vslot wheels on the Gantry are mounted with a corner-bracket. Each wheel has an adjusting part to change the position of the wheel to remove play with the Arm. ALSO for vertical leveling of the Z-axis. This leveling will be an item for assembly procedures ;-) > Checklist C031
AA015 | Endstops at Arm end and at some 650mm from end to limit the gantry movement, and to allow a Homing procedure in GRBL. The inner endstop is to prevent the Z-axis motor to touch the hexapod feet.
AA016 | Cabling management for Arm and Z-Axis added for bothe motor and endstop cabling. Via a cable-chain wrapping around on top of the round plate at bottom of hub provides the Arm-Z cabling to be connected to the hexapod feet, yet provide a 0-360 rotation with 0 being on the backside of the NFSROBOT.
AA017 | The cabling for the Endstop has a GX12-2 connector , the motor cable a GX16-4 connector. The connector houses are used to connect the cable-shields ultimately to Gnd of the 24V powersupply Gnd.
AA018 | To support the cabling of motors and endstops, brackets are added. For the Z-axis a connector is added at the gantry to allow disassembly of Z-axis from Arm.
AA019 | Testing shows microphone cable does not pick-up noise from motor cabling. So mic-cable can be added to cablechain. Cablechain from gantry to hub need more support because of microphone cable being added. > Checklist C030
AA020 | Cable harnessing of Mic cable, and for power cable plus XLR cable through central axle for measuring active speakers > Cecklist C032
AA021 | Vibration tansmission from motorblock to frame can be blocked by thin (0.25mm, 0.50mm) elastic rubber sheets in joints. Done, It reduces the transmission. A gluestick to 'stick' the rubber to the motor helps in the assembly.
AA022
AA023
AA024
AA025
AA026
AA027
AA028
AA029
AA030
AA031
AA032

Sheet: BOM-Hub-Arm-Assy
BOM for the Hub-Arm-Assembly |  | Naming as in F360 assembly file
Module | Part ID | Description | Quantity | Buy/Make | Notes
Arm-Assy-HUB: HUB | HUB001 | 16-as8-100x100-425mm | 1 | Buy | Both ends M8 threads need to be cut. Key is its stiffness!! Avaliability in cut to size is apparently an issue in Australia
Arm-Assy-HUB: HUB | HUB002 | Hoekprofiel-50x50x5-L100mm | 1 | Buy/Make | Drilling holes can be ordered, but one can make it self
Arm-Assy-HUB: HUB | HUB003 | M6x10-Allen | 8 | Buy
Arm-Assy-HUB: HUB | HUB004 | ECR-P8-6-TPM | 8 | Buy
Arm-Assy-HUB: HUB | HUB005 | KABELGOOT-ARM-Rups | 1 | Make | 3D printed, using PETG (Rapid PETG)
Arm-Assy-HUB: HUB | HUB006 | M6x10-Allen-Rnd-Head | 4 | Buy
Arm-Assy-HUB: HUB | HUB007 | ECR-P8-6-TPM | 4 | Buy
Arm-Assy-HUB: HUB | HUB008 | ALT-Kabelrups-Mount-Hub | 1 | Make | 3D printed, using PETG (Rapid PETG)
Arm-Assy-HUB: HUB | HUB009 | M6x10-Allen-Low-Head | 2 | Buy
Arm-Assy-HUB: HUB | HUB010 | ECR-P8-6-TPM | 2 | Buy
Arm-Assy-HUB: ONDERBLOK | LBB001 | OnderBlok-Lagerblok-50x72x12-bovendeel | 1 | Make | 3D printed, using PETG (Rapid PETG), to be glued to "Onderblok-Lagerblok onderdeel"
Arm-Assy-HUB: ONDERBLOK | LBB002 | OnderBlok-Lagerblok-50x72x12-onderdeel | 1 | Make | 3D printed, using PETG (Rapid PETG), to be glued to "Onderblok-Lagerblok bovendeel"
Arm-Assy-HUB: ONDERBLOK | LBB003 | Naaf-onderblok-50x72x12 | 1 | Make | 3D printed, using PETG (Rapid PETG), must have a tight fit on the centerpole and on the bearing.
Arm-Assy-HUB: ONDERBLOK | LBB004 | Flens-Onderblok | 1 | Make | 3D printed, using PETG (Rapid PETG), to be screwed (metalscrews)onto "Onderblok-Lagerblok onderdeel" But may also be glued.
Arm-Assy-HUB: ONDERBLOK | LBB005 | M8x25-Allen | 4 | Buy
Arm-Assy-HUB: ONDERBLOK | LBB006 | Leather-Washer-11x4x3mm | 4 | Make | , may be bigger, I used leather as a vibrous material to dampen structure borne vibrations. A thick felt will do as well
Arm-Assy-HUB: ONDERBLOK | LBB007 | Kogellager 72x50x12 6910-2RS | 1 | Buy | Bearing
Arm-Assy-HUB: BOVENBLOK | UBB001 | BovenBlok-Lagerblok-50x65x7 | 1 | Make | 3D printed, using PETG (Rapid PETG), the 10mm holes need to be tight fit for collar-screws, reaming is an option.
Arm-Assy-HUB: BOVENBLOK | UBB002 | LAGERRING | 2 | Make | 3D printed, using PETG (Rapid PETG), this ring to be mounted (glued) in bearing block after mounting bearing.
Arm-Assy-HUB: BOVENBLOK | UBB003 | Naaf-Bovenblok-50x65x7 | 1 | Make | 3D printed, using PETG (Rapid PETG), must have a tight fit on the centerpole and on the bearing.
Arm-Assy-HUB: BOVENBLOK | UBB004 | bearing_6810_2rs-65x50x7 | 1 | Buy
Arm-Assy-HUB: BOVENBLOK | UBB005 | Collar-Screw-10-M8-16 | 4 | Buy
Arm-Assy-HUB: BOVENBLOK | UBB006 | Low Profile Screw M5 x 20 | 12 | Buy | The middle 4 can be skipped I believe now. The most important is the firm mount on the alu profiles of the Arm!
Arm-Assy-HUB: BOVENBLOK | UBB007 | ECR-P6-5-TPM | 12 | Buy
Arm-Assy-ARM: ARM-MOTOR-MOUNT | ARM001 | ARM-Motor-Steun-Motor | 1 | Make | 3D printed, using PETG (Rapid PETG) . I think too rigid, considering an alternative design.
Arm-Assy-ARM: ARM-MOTOR-MOUNT | ARM002 | ARM-Motor-Steun-Pulley | 1 | Make | 3D printed, using PETG (Rapid PETG) . Bearing slots to ream, bearings must tight fit.
Arm-Assy-ARM: ARM-MOTOR-MOUNT | ARM003 | GT2-20t-8mm-Pulley-Motorkant | 1 | Buy
Arm-Assy-ARM: ARM-MOTOR-MOUNT | ARM004 | ARM-Motorsteun-As 8mmx73mm | 1 | Buy | Bought a bar hi-precision steel with a H7 or H8 tolerance, and cut it to size.
Arm-Assy-ARM: ARM-MOTOR-MOUNT | ARM005 | Flenslager-8x16x5mm | 2 | Buy
Arm-Assy-ARM: ARM-MOTOR-MOUNT | ARM006 | Arm-VULSTUK-10mm-Dik | 1 | Make | 3D printed, using PETG (Rapid PETG). Is a fill piece.
Arm-Assy-ARM: ARM-MOTOR-MOUNT | ARM007 | ArmMotor-C-beam-80x40 | 1 | Buy | To make a rigid connection of arm to hub!
Arm-Assy-ARM: ARM-MOTOR-MOUNT | ARM008 | M6x50-Allen | 3 | Buy
Arm-Assy-ARM: ARM-MOTOR-MOUNT | ARM009 | ECR-MA-P6-5 | 13 | Buy
Arm-Assy-ARM: ARM-MOTOR-MOUNT | ARM010 | Low Profile Screw M5x10 | 4 | Buy
Arm-Assy-ARM: ARM-MOTOR-MOUNT | ARM011 | Low Profile Screw M5x16 | 6 | Buy
Arm-Assy-ARM: ARM-MOTOR-MOUNT | ARM012 | MH2025-5-8-ElastFlexCoupling v1 | 1 | Buy | for 5mm motor axle and 8mm axle diameter.
Arm-Assy-ARM: ARM-MOTOR-MOUNT | ARM013 | Rubber shim 0.25mm thick | 1 | Make | To place between motor and motormount to reduce vribration transmission (a bit)
Arm-Assy-ARM: ARM-EIND-SPANBLOK | ARM014 | GT2-20t-8mm-Pulley-Eind-steun | 1 | BUY
Arm-Assy-ARM: ARM-EIND-SPANBLOK | ARM015 | ARM-Eind-Steun-Eindplaat | 1 | Make | 3D printed, using PETG (Rapid PETG) .
Arm-Assy-ARM: ARM-EIND-SPANBLOK | ARM016 | ARM-Eind-Steun-Lagerblok | 1 | Make | 3D printed, using PETG (Rapid PETG) . Bearing slots to ream, bearings must tight fit.
Arm-Assy-ARM: ARM-EIND-SPANBLOK | ARM017 | ARM-Eind-Bus10x8.1x6.5mm | 1 | Make | 3D printed, using PETG (Rapid PETG) . To reduce axial play
Arm-Assy-ARM: ARM-EIND-SPANBLOK | ARM018 | Flenslager-8x16x5mm | 2 | Buy
Arm-Assy-ARM: ARM-EIND-SPANBLOK | ARM019 | ARM-Eind-As 8x38mm |  | Buy | Bought a bar hi-precision steel with a H7 or H8 tolerance, and cut it to size.
Arm-Assy-ARM: ARM-EIND-SPANBLOK | ARM020 | Low Profile Screw M5x35 | 2 | Buy
Arm-Assy-ARM: ARM-EIND-SPANBLOK | ARM021 | M5-Washer | 6 | Buy
Arm-Assy-ARM: ARM-EIND-SPANBLOK | ARM022 | M5-NUT-Hexagon-Blocking | 2 | Buy
Arm-Assy-ARM: ARM-EIND-SPANBLOK | ARM023 | Low Profile Screw M5x25 | 4 | Buy
Arm-Assy-ARM: ARM-EIND-SPANBLOK | ARM024 | Low Profile Screw M5x10 | 2 | Buy
Arm-Assy-ARM: ARM-EIND-SPANBLOK | ARM025 | ECR-MA-P6-5 | 2 | Buy
Arm-Assy-ARM: ARM-MID-Spanblok | ARM026 | ARM-Mid-Span-Blok | 1 | Make | 3D printed, using PETG (Rapid PETG) .
Arm-Assy-ARM: ARM-MID-Spanblok | ARM027 | Gladde-span-pulley-5mm-as, with bearings | 1 | Buy
Arm-Assy-ARM: ARM-MID-Spanblok | ARM028 | As-5mm - 39mm | 1 | Buy | Bought a bar hi-precision steel with a H7 or H8 tolerance, and cut it to size.
Arm-Assy-ARM: ARM-MID-Spanblok | ARM029 | Low Profile Screw M5x10 | 4 | Buy
Arm-Assy-ARM: ARM-MID-Spanblok | ARM030 | ECR-MA-P6-5 | 4 | Buy
Arm-Assy-ARM-GT2 | ARM031 | GT2-9mm open end belt ~ 3m | 1 | Buy | Typically sold by 5 or 10m, I purchased a 10m roll as it is also used in the Z-axis assy
Arm-Assy-ARM: ARM-Slanted-Support-Mount-Adjust | ARM032 | SPANBLOK-Armsteun | 1 | Make | 3D printed, using PETG (Rapid PETG) . To provide a adjustable position for squaring HUB-ARM
Arm-Assy-ARM: ARM-Slanted-Support-Mount-Adjust | ARM033 | Low Profile Screw M5x16 | 2 | Buy
Arm-Assy-ARM: ARM-Slanted-Support-Mount-Adjust | ARM034 | ECR-MA-P6-5 | 4 | Buy
Arm-Assy-ARM: ARM-Slanted-Support-Mount-Adjust | ARM035 | M8x35-Hexagon | 1 | Buy
Arm-Assy-ARM: ARM-Slanted-Support-Mount-Adjust | ARM036 | Low Profile Screw M5x10 | 2 | Buy
Arm-Assy-ARM: ARM-Slanted-Support-Mount-Adjust | ARM037 | M6x10-Rnd-Head | 2 | Buy
Arm-Assy-ARM: ARM-Slanted-Support-Mount-Adjust | ARM038 | ECR-P8-6-TPM | 2 | Buy
Arm-Assy-ARM: ARM-Slanted-Support-Mount-Adjust | ARM039 | V-slot 20x40 675mm | 1 | Buy
Arm-Assy-ARM: ARM-Slanted-Support-Mount-Adjust | ARM040 | Pivot-joint-for-20x40-profile | 2 | Buy
Arm-Assy-ARM: Arm-C-Beam-80x40st | ARM041 | Arm-C-beam-80x40 L=1244mm | 1 | Buy
KABEL-HARNAS-Gantry | ARM042 | ALT-Gantry-Junctionbox | 1 | Make | 3D printed, using PETG (Rapid PETG) .
KABEL-HARNAS-Gantry | ARM043 | Cable-Secure-Clip | 1 | Make | 3D printed, using PETG (Rapid PETG) .
KABEL-HARNAS-Gantry | ARM044 | Cable-Chain-support | 1 | Make | 3D printed, using PETG (Rapid PETG) .
KABEL-HARNAS-Gantry | ARM045 | Low Profile Screw M5_M5 x 8 | 4 | Buy
KABEL-HARNAS-Gantry | ARM046 | ECR-MA-P6-5 | 2 | Buy
ENDSTOPS | ARM047 | ARM-Endstop-Bracket | 2 | Buy
Damping-Block-Blue-Fibres | ARM048 | Damping-Block-Blue-Fibres | 1 | Buy | Damping material to mitigate reflections.
Gantry-2080x | GANTRY01 | V-Slot-80x20 250mm | 1 | Buy
Gantry-2080x | GANTRY02 | WHK_VSLOT_SLD_XTREM | 4 | Buy | Wheels of hard plastic, including bearings and shim(s)
Gantry-2080x | GANTRY03 | Angle | 4 | Buy | Aluminium 90 deg angle for mounting v-slot
Gantry-2080x | GANTRY04 | Belt-Connector-Tensioner | 2 | Make | 3D printed, using PETG (Rapid PETG) .
Gantry-2080x | GANTRY05 | Precision Shim 10 x 5 x 1 | 4 | Buy
Gantry-2080x | GANTRY06 | Low Profile Screw M5_M5 x 25 | 4 | Buy
Gantry-2080x | GANTRY07 | HEX10-Excenter | 4 | Buy
Gantry-2080x | GANTRY08 | ECR-MA-P6-5 | 8 | Buy
Gantry-2080x | GANTRY09 | DBL-ECR-M5-P6 | 4 | Buy
Gantry-2080x | GANTRY10 | Low Profile Screw M5_M5 x 15 | 4 | Buy
Gantry-2080x | GANTRY11 | Low Profile Screw M5_M5 x 8 | 4 | Buy

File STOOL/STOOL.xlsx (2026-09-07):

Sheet: STOOL
# | Decisions regarding the STOOL of the HALS Mechatronics
Stool001 | To mount a DUT, a platform is needed on top of the end of the central pillar. These are 3D printed and must make sure they fit very tight on the Central Pillar, and a M4 bolt to secure.
Stool002 | 2 sizes stool are made: a 90x90mm and a 200x200mm size.
Stool003 | For the 200x200mm size, upon suggestion of Mark Kravchenko, a wrapping band is mounted.
Stool004 | Calibration triangle 30mm high, that fits tightly in center hole of stool, its desing such that the calibration side of the triangle is on the PHI axis, its 1mm thickness therefore behind the PHI-axis.
Stool005 | The triangle is flexible to prevent damaging the microphone when jogging too far in. Decided for 1mm thickness, also in extreme case will flip backwards.

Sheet: STOOL; BOM
BOM for the HALS-Mechatronics STOOL
Module | Part ID | Description | Quantity | Buy/Make | Notes
STOOL | STOOL001 | 90x90mm stool | 1 | Make | 3D printed, using PETG (Rapid PETG)
STOOL | STOOL002 | 200x200mm stool | 2 | Make | 3D printed, using PETG (Rapid PETG)
STOOL | STOOL003 | Strap band for 200x200mm stool | 3 | Buy | mount on bottom of stool and secure with MSPolymer glue
STOOL | STOOL004 | M4x16 bolt (or headless allen screw M4) | 2 | Buy | to secure placement of stool, especially prevent rotation.
STOOL | STOOL005 | Calibration triangle 30mm high | 1 | Make | 3D printed, using PETG (Rapid PETG), in 2 parts. These to be glued with cyanoacrylate, whilsth aligning carefully.

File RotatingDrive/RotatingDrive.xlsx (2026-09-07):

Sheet: Rotating-Drive
# | Decisions
RD001 | The rotating drive is the most difficult for me to determine the right motor reduction and sizing of belt etc on beforehand. Basically because i have little understanding of the stepper motor behaviour.
RD002 | So i made a proto and found that probable the reduction was not great enough for the motor used.
RD003 | So a second proto made and this one did rotate the test arm in a controllable way up to ~1 degree steps. Use of a reduction gearing of 10:1 plus HTD3M-9mm toothed belt and a 270:20 pulley ratio. Thus 135:1. With appropriate GRBL settings for acceleration and speed a 1 degree step is possible and a 180 degree sweep in ~ 9 seconds. Checklist C002, Done.
RD004 | Yet the proto also showed the need to control the belt tension as a rocking motion at start en stop of a step is direct result of not tight belt tensioning. So checklist C003. Done.
RD005 | Another issue is that all the belt lenth calculators i could access on the internet gave wrong results, very curious. But it means i have to device a calculator in Fusion 360 to satisfy the need. Checklist C004. Stopped, the https://www.dold-mechatronik.de/Zahnriemen provides a close enough ressult, around 1mm tolerance.
RD006 | The connection of the PHI-rotator on the tripod enhanced to be rocksolid stiff connected to tripod, including leaving room for fastening knob of tripod. Checklist C003, Done.
RD007 | For the drive to calculate the needed torque and speed/accel the formulation to be adapted. I have no feeling yet with the steppermotor behaviour incombination with GRBL settings. Checklist C007 For now i just use one of the strongest Nema17 size motor and a 10:1 reduction gear. It works very well!!
RD008 | The casing initially planned of the drive and is also needed for supporting the cable spiral coming from the arm -assy and going into the foot. Checklist C013 . Decided not to make a casing. Instead I added 2 rigs angled 45 degrees from central axis and on one support an endplate to block the cable-chain from moving too much. So far this works fine.
RD009 | The chassis as it is now suffices for the first working version of NFSROBOT. But will be replaced with a better dimensioning of belt-length > distance between centerlines and belt tensioners > Checklist C014 Done, see also RD011
RD010 | ~~Also a platform or rig is needed to guide the cable-chain spiral. For now 2 rigs are used.~~
RD011 | Belt length now is 1068 teeth (HTD3M) , The drive pully is now on separate axle(8mm) and motor connected via backlash free flex coupling. Therefore higher pretensioning is possible without overloading the reduction gear axle.The whole drive assy is adjustable and replacable if needed. The tensioning is by means of a sliding bracket as used on first chassis. Simply works very fine. For calibration purposes a small frame is added to the main pully , 1, 45, 90 degreemarks, and a Vernier-scale is added to see the tolerance (theoretically 0.1 degree)
RD012 | When installed on NFSROBOT, need to calibrate and test > C024 > Done
RD013 | As motor the first choice is the 17HE24-2104S because of its initial high torque. But this also means that fast movement/rotation (Max Feedrate) is more limited than the 17HS24-2104S. See also MOTION
RD014 | The PHI axis endstop (microswitch) mount is now made of a bracket with enough adjustment room to precisely place the "click".
RD015 | For M5 and M8 bolts the holes are threaded , use a bit of isopropyl-alcohol to reduce friction and temperature raising. Practice this before final.
RD016 | The Nema17 motor cable connection requires an endcap to secure the cable mount to the motor.
RD017 | Once motor pulley aligned in height, make sure both allen screws are tight
RD018
RD019
RD020

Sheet: BOM Rotating Drive
BOM for the HALS-Mechatronics Rotating Drive
Module | Part ID | Description | Quantity | Buy/Make | Notes
RotatingDrive-CHASSIS | RD-CH001 | HUB as Central part to fit on tripod mount | 1 | Make | Specific for the gravity tripod, using 3d Model: TripodCentralMount-Replica. HUB glued into the main chassis beam, while being very well aligned. Degrease the surfaces thoroughly!
RotatingDrive-CHASSIS | RD-CH002 | CHASSIS (Main chassis beam) | 1 | Make | Specific for the closed belt size HTD3M-1068mm ; 3D printed, using PETG (Rapid PETG)
RotatingDrive-CHASSIS | RD-CH003 | CableChain-mount- Chassis-side | 1 | Make | 3D printed, using PETG (Rapid PETG), glued to chassis beam with cyanoacrylarte (degrease first!)
RotatingDrive-CHASSIS | RD-CH004 | Cable-Clamp-03 | 1 | Make | 3D printed, using PETG (Rapid PETG)
RotatingDrive-CHASSIS | RD-CH005 | Cablechain-L-support Part-1 | 1 | Make | 3D printed, using PETG (Rapid PETG), glued to chassis beam with cyanoacrylarte (degrease first!)
RotatingDrive-CHASSIS | RD-CH006 | Cablechain-R-support Part-1 | 1 | Make | 3D printed, using PETG (Rapid PETG), glued to chassis beam with cyanoacrylarte (degrease first!)
RotatingDrive-CHASSIS | RD-CH007 | Cablechain-Support-Part-2 | 2 | Make | 3D printed, using PETG (Rapid PETG), glued to support (degrease first!)
RotatingDrive-CHASSIS | RD-CH008 | Cablechain-Stop | 1 | Make | 3D printed, using PETG (Rapid PETG), glued to end of Part-2 (degrease first!)
RotatingDrive-CHASSIS | RD-CH009 | Swich triangle to trigger endstop switch | 1 | Make | 3D printed, using PETG (Rapid PETG), glued to main pulley (degrease first!)
RotatingDrive-CHASSIS | RD-CH010 | Mswitch-bracket | 1 | Make | 3D printed, using PETG (Rapid PETG)
RotatingDrive-CHASSIS | RD-CH011 | Mswitch-bracket-Clamp | 1 | Make | 3D printed, using PETG (Rapid PETG)
RotatingDrive-CHASSIS | RD-CH012 | M3x20 bolt + nut | 2 | Buy | For M-switch bracket clamp
RotatingDrive-Motor-Pulley-Assy | RD-MP001 | MotorMount-01 | 1 | Make | 3D printed, using PETG (Rapid PETG)
RotatingDrive-Motor-Pulley-Assy | RD-MP002 | MotorMount-filling plate-1mm | 1 | Make | If needed, and this can be of rubber
RotatingDrive-Motor-Pulley-Assy | RD-MP003 | Axle-H7-8mmx65mm | 1 | Buy | Typically sold as a bar, some suppliers provide cut to size as option.
RotatingDrive-Motor-Pulley-Assy | RD-MP004 | Stepper motor 17HE24-2104S | 1 | Buy | https://www.omc-stepperonline.com/
RotatingDrive-Motor-Pulley-Assy | RD-MP005 | M4x16 allen screw plus washer | 4 | Buy | to mount motor-reductiongear assy
RotatingDrive-Motor-Pulley-Assy | RD-MP006 | HTD3M 9mm 20t pulley 8mm axle | 1 | Buy | https://www.dold-mechatronik.de/
RotatingDrive-Motor-Pulley-Assy | RD-MP007 | Flathead-bolt-M5x15mm (www.systeal.com) | 3 | Buy | https://www.systeal.com reference: VIS-XP-CBM5-15
RotatingDrive-Motor-Pulley-Assy | RD-MP008 | Flange bearing-8x16x5mm | 2 | Buy
RotatingDrive-Motor-Pulley-Assy | RD-MP009 | Reduction gear EG17-G10 | 1 | Buy | https://www.omc-stepperonline.com/
RotatingDrive-Motor-Pulley-Assy | RD-MP010 | MH2025-8-8-ElastFlexCoupling | 1 | Buy
RotatingDrive-Motor-Pulley-Assy | RD-MP011 | NEMA17-ENDCAP-CABLING | 1 | Make | 3D printed, using PETG (Rapid PETG), for a rigid mounting of the feed cable, see also MOTION or cable choice and connection!
RotatingDrive-Motor-Pulley-Assy | RD-MP012 | Allen M3x16 + nut | 2 | Buy | for tight ENDCAP on motor, see also tab MOTION for cable choice and connection!
RotatingDrive-Motor-Pulley-Assy | RD-MP013 | HTD3M-1068mm Closed belt |  | Buy | https://www.dold-mechatronik.de/
RotatingDrive-Motor-Pulley-Assy | RD-MP014 | Allen bolt M4x15 + washer | 4 | Buy | To mount the motor-reductiongear combo to the Motormount.
RotatingDrive-Motor-Pulley-Assy | RD-MP015 | Countersunk-screw 3.2x10mm | 4 | Buy | To mount the Bottom bearing flancge to the 270t main pulley. Note: with thick leather or similar fibrous material washers in between.
RotatingDrive-Tensioner-System | RD-TS001 | Tension roller-guide | 1 | Make | 3D printed, using PETG (Rapid PETG), glued to chassis beam with cyanoacrylarte (degrease first!)
RotatingDrive-Tensioner-System | RD-TS002 | Tension roller-frame | 1 | Make | 3D printed, using PETG (Rapid PETG)
RotatingDrive-Tensioner-System | RD-TS003 | Flange bearing-8x16x5mm | 4 | Buy
RotatingDrive-Tensioner-System | RD-TS004 | Bearing-8x16x5mm | 2 | Buy
RotatingDrive-Tensioner-System | RD-TS005 | Axle-H7-8mmx28mm | 2 | Buy | Typically sold as a bar, some suppliers provide cut to size as option.
RotatingDrive-Tensioner-System | RD-TS006 | Bolt M8x35mm | 1 | Buy | To bolt down the tension roller-frame.
RotatingDrive-Tensioner-System | RD-TS007 | Flathead-bolt-M5x12mm (www.systeal.com) | 2 | Buy | A flat-head bolt with allen key slot. Its use is to adjust the motor-pulley-assy alignment.
RotatingDrive-Main-Pulley | RD-MP001 | Main pulley HTD3M-9mm-270t | 1 | Make | 3D printed, using PETG (Rapid PETG). ! Make sure the dimensional correctness of your printer!
RotatingDrive-Main-Pulley | RD-MP002 | Bearing 65x50x7mm 6810-2RS | 1 | Buy | Must fit thightly in main pulley and on HUB

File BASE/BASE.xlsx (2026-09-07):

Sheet: BASE; Foot & main axle
# | Decisions regarding the BASE of the HALS Mechatronics
Base001 | I choose the Gravity TSP 2512B, simply because of its robustness, large foot area, all components of metal and tubing of steel
Base002 | For the moment I only use the base tube of the central axis, its diameter is ~41.3mm . The extenstion tube is not used, it is also not very straight.
Base003 | Initial stability tests with proto show that over short axis tipping will happen. (330 vs 660mm). A wooden construction added to the design, Checklist C001. Done, I made a mountable construction of 3 plywood legs with 3D printed brackets to mount these to the low end of the pillar, and on the bottom end of the legs to join them. These legs will also be used to mount the power supply and the driver electronics. Basically is it now a HexaPod. Superseded, see Base011 and checklist C028
Base004 | The metal base connecting the 3 legs is also the part that holds securely the rotating device. It has a sort of collar. A digital model is made of this collar, so the central hub of the rotating drive fits over it. This model is now expanded a bit to provide more stiffness.
Base005 | The central pillar is hollow, and has a 15mm hole close to the top, in order to pass the loudspeaker cable through the hollow pillar near the bottom a hole is needed. ~15mm. Revised, the loudspeaker cable goes via the Stool into the central pillar, still need a hole in the bottom of the pillar.
Base006 | A loudspeakercable to add, type cordial CLS425 , a 4 core 2.5mm2 cable so 2 connections can be made. For me the connectors will be Neutrik Speakon. > Checklist C006 Addendum: For first working proto a 5m cable with bananaplugs is used.
Base007 | Stool for DUT A stool is designed and printed to put a DUT on, it is a 200x200mm square top. Upon request for somehow fix the DUT i included a fastening belt to secure DUT on stool. Checklist C008, done.
Base008 | The tripod legs at the end have a rubber cap, these are replaced by 3D printed caps holding a M8 leveling foot. For the M8 leveling screw, the M8 thread is cut in the 3D printed caps. To clamp the endcap a M4 bolt/nut is used
Base009 | The procedure for leveling needs to be written. > Checklist C031
Base010 | Rubber feet to raise the NFSROBOT a bit for Tom and to prevent sliding when touching > Checklist C019 Addendum: feet are too soft so dismissed. Need hard blocks , wood or similar if some raising is needed.
Base011 | Decided to add mass to the end of the tripod legs, as the wooden add-on legs after several assembly round showed too much play. And especially with the mic assy at end of arm it is clear that some mass is needed. The mass I decided for is ~6- 7 kg. Purchased tiles of 30x30x4cm = ~7kg > Checklist C028
Base012

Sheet: BASE; BOM
BOM for the HALS-Mechatronics BASE
Module | Part ID | Description | Quantity | Buy/Make | Notes
BASE | BASE001 | Gravity TSP 2512B tripod | 1 | Buy | Steel, very stiff
BASE | BASE002 | Level adjustment M8x24 foot/screw | 3 | Buy
BASE | BASE003 | Endcaps on tripod leg for level adjustment screw | 3 | Make | 3D printed, using PETG (Rapid PETG)
BASE | BASE004 | Mass-plateau bracket | 3 | Make | 3D printed, using PETG (Rapid PETG)
BASE | BASE005 | Extra Mass ~ 7kg casting mould, 2 parts | 2 | Make | 3D printed, using PETG (Rapid PETG)
BASE | BASE006 | Extra Mass ~ 7kg on tripod leg | 3 | Buy/Make | Essential to prevent tipping, a tile or a self-made concrete mass see 3D model
BASE | BASE007 | Mass mounting bracket | 3 | Make | 3D printed using PETG (Rapid PETG), glued with MSPolymer to mass.
BASE | BASE008 | M4x16 plus washer and nut | 3 | Buy | M4 bolt/nut for clamping endcap

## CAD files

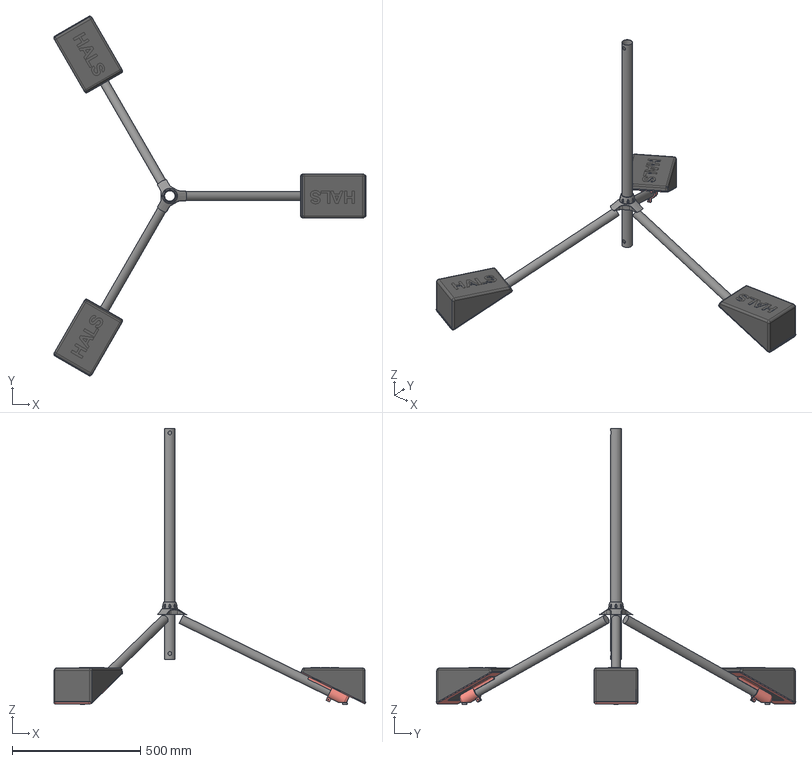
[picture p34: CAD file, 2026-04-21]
BASE/HALS-BASE-Assy.step
1214.1 x 1399.7 x 1075.0 mm

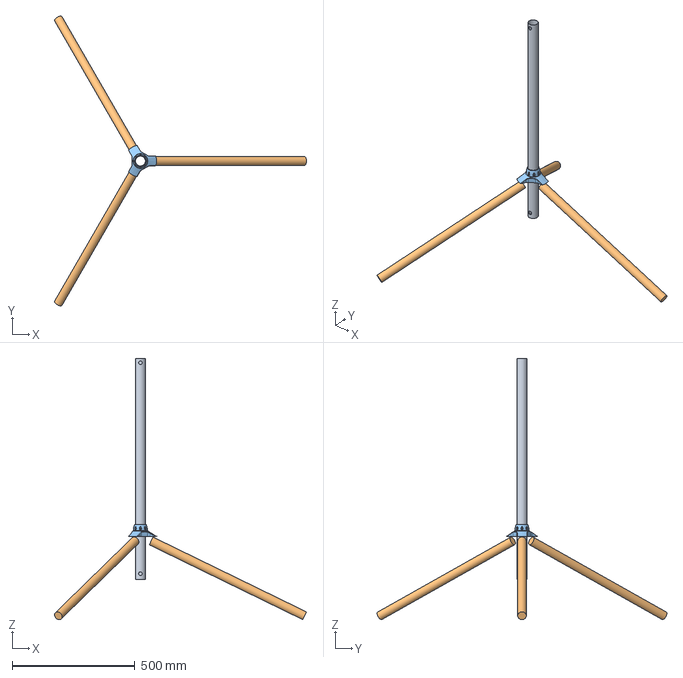
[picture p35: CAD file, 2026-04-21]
BASE/Gravity-Tripod-01.step
1025.7 x 1179.4 x 1063.4 mm

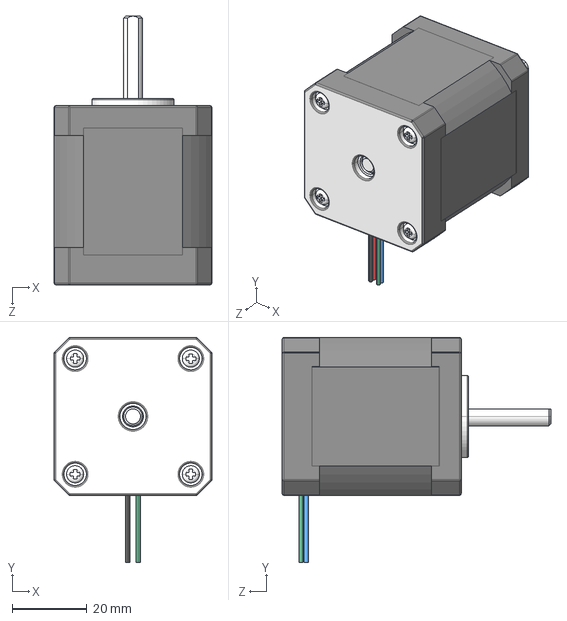
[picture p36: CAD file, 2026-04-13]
MOTION&CABLING/GitHub-MOTION (Electronics-Motors)/BTT-Stuff/OMC-STEPPERONLINE/17HS19-2004S2.STEP
42.3 x 60.3 x 72.0 mm

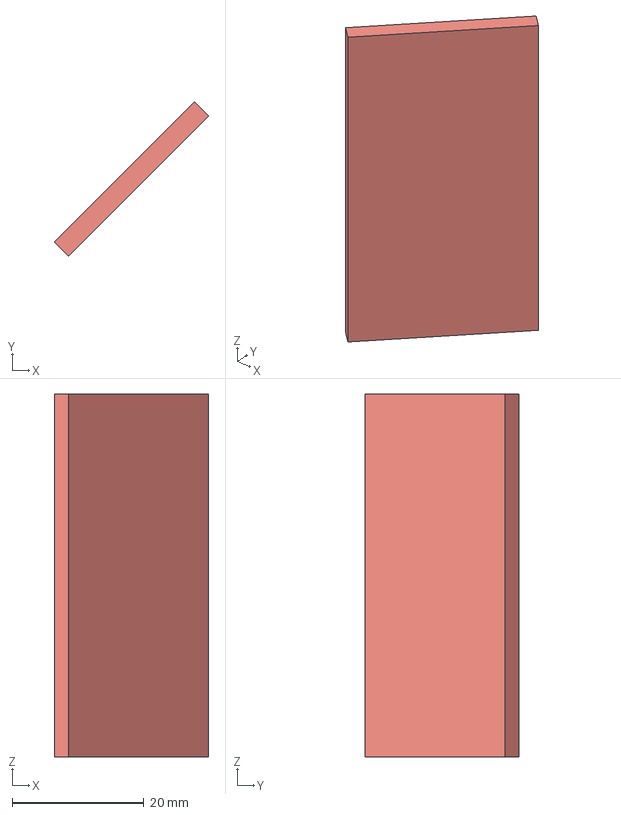
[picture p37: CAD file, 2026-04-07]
RotatingDrive/CableChain-Stop.step
23.3 x 23.3 x 55.0 mm

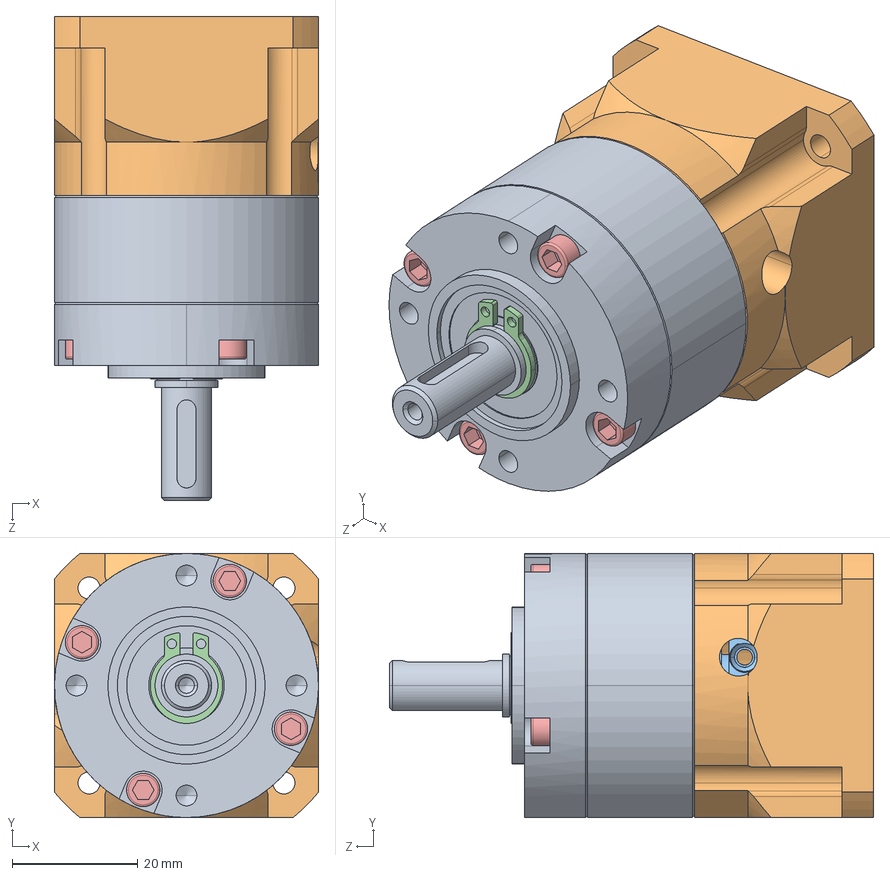
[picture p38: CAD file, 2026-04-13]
MOTION&CABLING/GitHub-MOTION (Electronics-Motors)/BTT-Stuff/OMC-STEPPERONLINE/EG17-G5.STEP
42.0 x 42.0 x 77.0 mm
EG17 shaft
nema17input flange
input shaft
Φ10circlip
M3hexagon socket head cap screw x 8

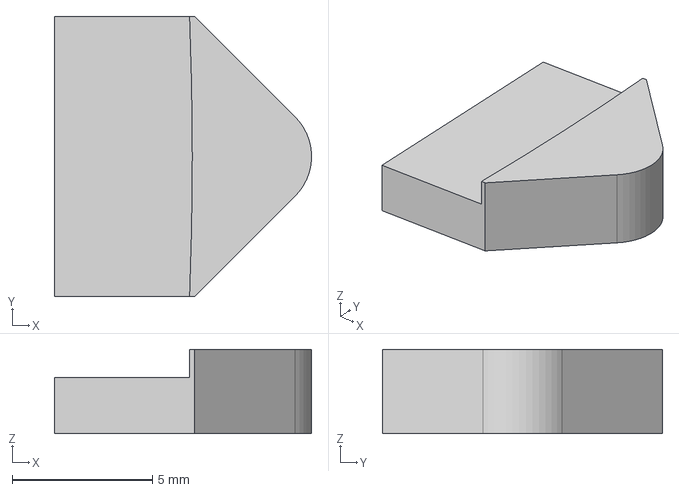
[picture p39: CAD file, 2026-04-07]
RotatingDrive/Switch-Triangle.step
9.17 x 10.0 x 3.00 mm

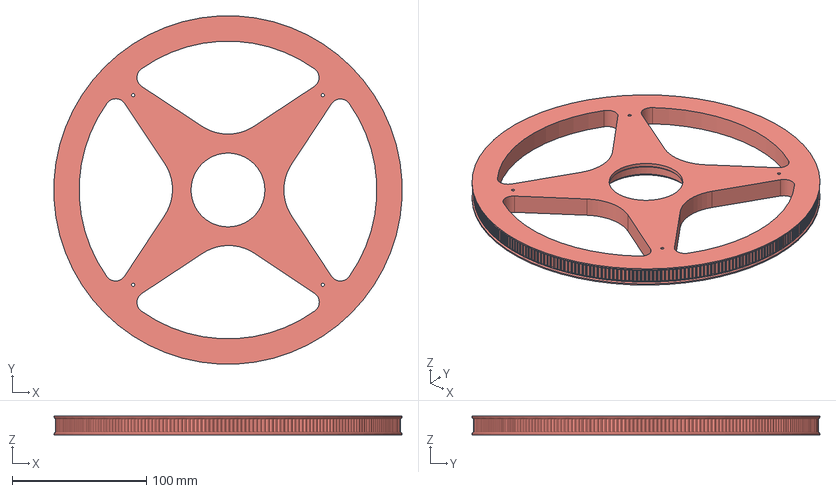
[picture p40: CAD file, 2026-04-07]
RotatingDrive/HTD3M-270T-01.step
259.5 x 259.5 x 14.0 mm

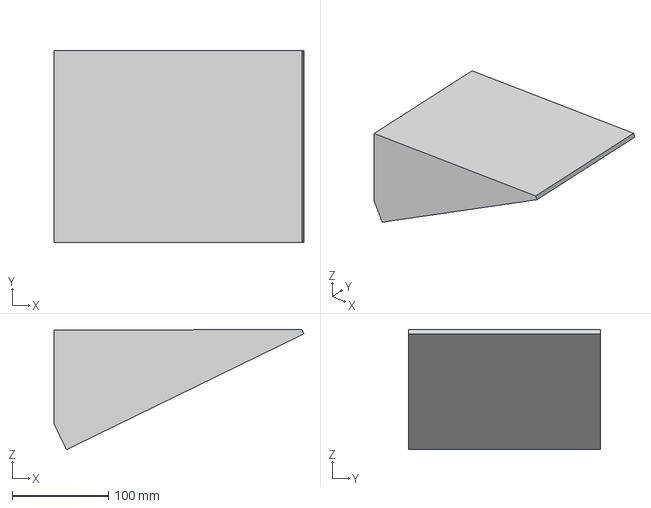
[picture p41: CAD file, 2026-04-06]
BASE/TripodLeg-Endcaps-WeightBrackets-ALTMASS.step
260.2 x 200.0 x 125.2 mm

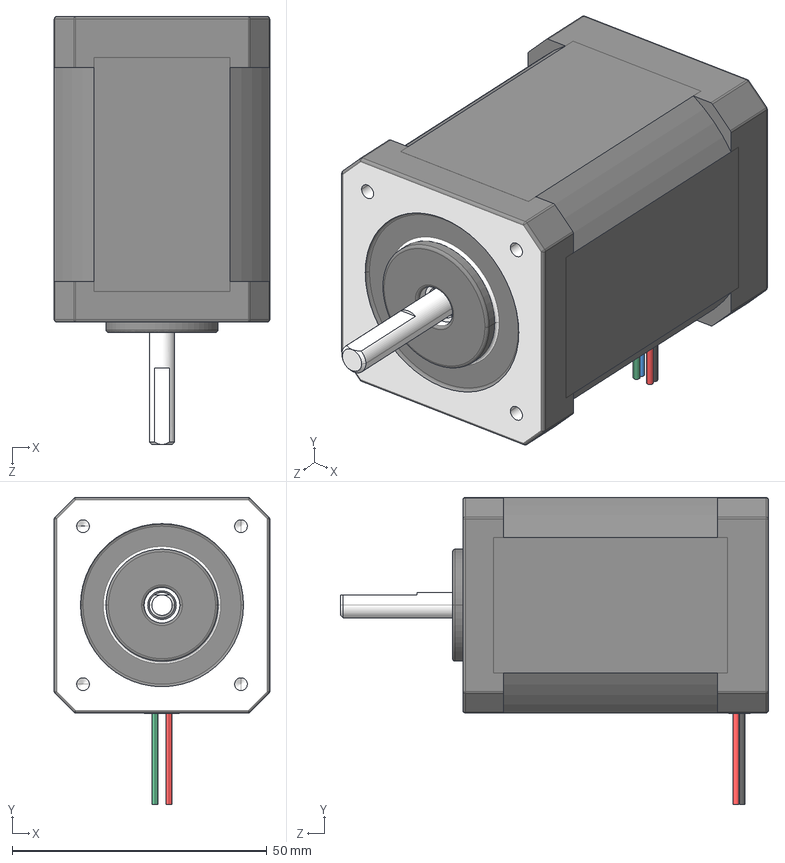
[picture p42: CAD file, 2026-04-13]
MOTION&CABLING/GitHub-MOTION (Electronics-Motors)/BTT-Stuff/OMC-STEPPERONLINE/17HS24-0644S.STEP
42.3 x 60.3 x 84.0 mm

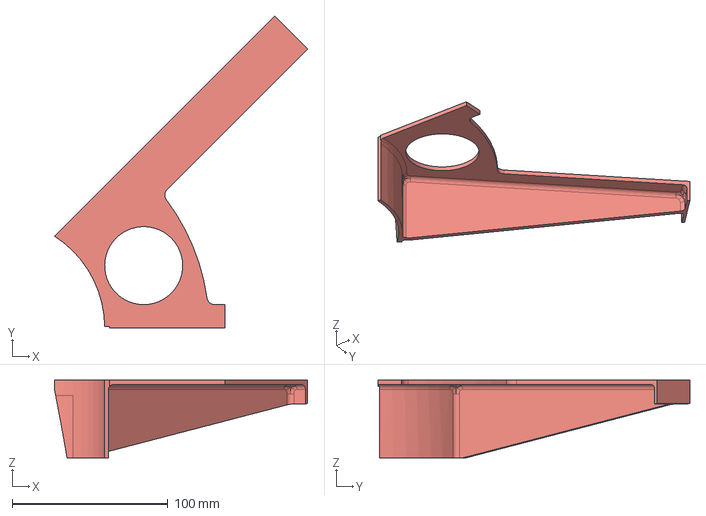
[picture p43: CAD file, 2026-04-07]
RotatingDrive/Cablechain-L-support Part-1.step
162.4 x 200.1 x 50.0 mm

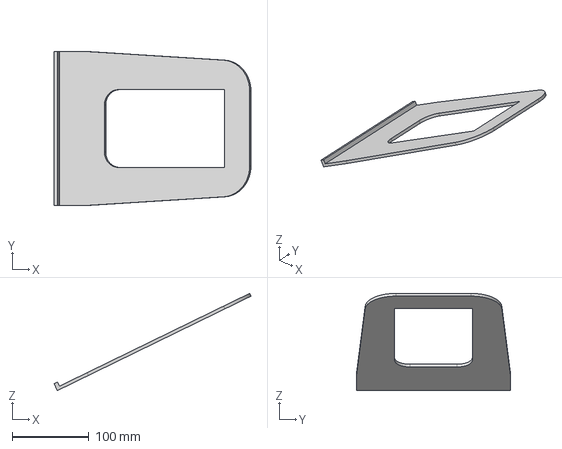
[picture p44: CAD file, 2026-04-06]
BASE/TripodLeg-Endcaps-WeightBrackets-Mass-Carrier.step
256.0 x 200.0 x 126.3 mm

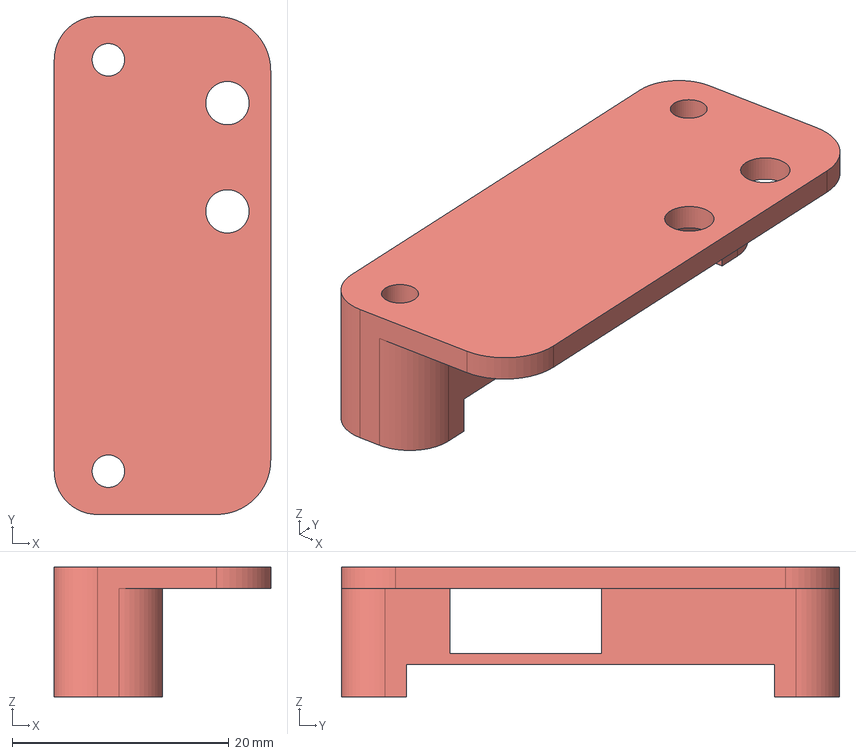
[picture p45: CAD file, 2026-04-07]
RotatingDrive/Mswitch-Bracket.step
20.0 x 46.0 x 12.0 mm

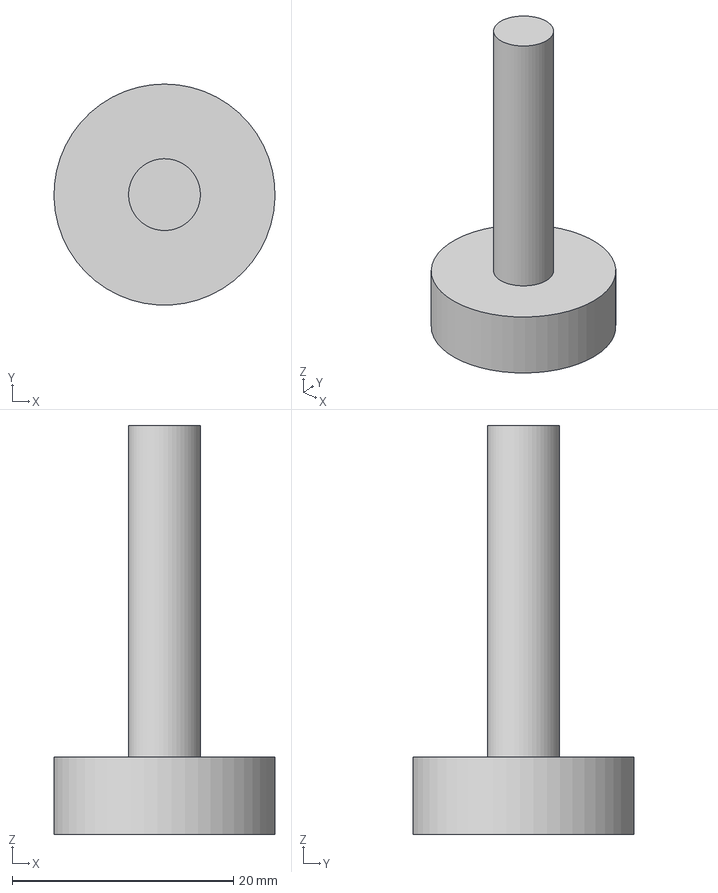
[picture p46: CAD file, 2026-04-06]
BASE/TripodLeg-Endcaps-AdjustFoot.step
20.0 x 20.0 x 37.0 mm

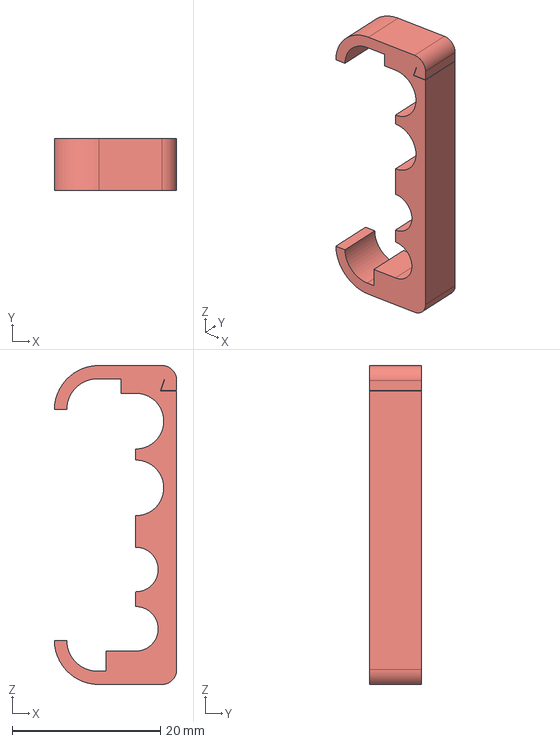
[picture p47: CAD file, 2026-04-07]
RotatingDrive/Cable-Clamp.step
16.5 x 7.00 x 43.0 mm

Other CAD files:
BASE/Gravity-Tripod.3mf
MOTION&CABLING/GitHub-MOTION (Electronics-Motors)/BTT-Stuff/OMC-STEPPERONLINE/17HS19-2504S.STEP
BASE/TripodLeg-Mass-Plateau.step
RotatingDrive/Tension-Roller-Frame.step
BASE/HALS-BASE-Assy.f3z
BASE/HALS-Base-Assy.FCStd
BASE/TripodLeg-Endcap-WeightBrackes-adjust-foot.step
BASE/TripodLeg-Endcaps-WeightBrackets.f3d
BASE/TripodLeg-Endcaps-WeightBrackets.f3z
BASE/TripodLeg-Endcaps.step
HALS-Total.f3z
RotatingDrive/CableChain-Mount-Chassis-Side.step
RotatingDrive/Cablechain-R-support Part-1.step
RotatingDrive/Cablechain-Support-Part-2.step
RotatingDrive/HALS-Rotating-DriveHTD3M-270t-20t-1068mmx.f3z
RotatingDrive/HTD3M-270T-01.f3z
RotatingDrive/HTD3M-270t-20t-1068mm-Chassis-CHASSIS.step
RotatingDrive/HTD3M-270t-20t-1068mm-Chassis-HUB.step
RotatingDrive/HTD3M-270t-20t-1068mm-Chassis-MotorMount-01.step
RotatingDrive/HTD3M-270t-20t-1068mm-Chassis-V3.f3d
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

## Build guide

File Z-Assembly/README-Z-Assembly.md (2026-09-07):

## HALS-Mechatronics: Z-axis-assembly

# The Z-Axis-Assembly
The Z-axis assembly is the complete unit for the Z-movement of the microphone. And is mounted on the gantry of the Arm
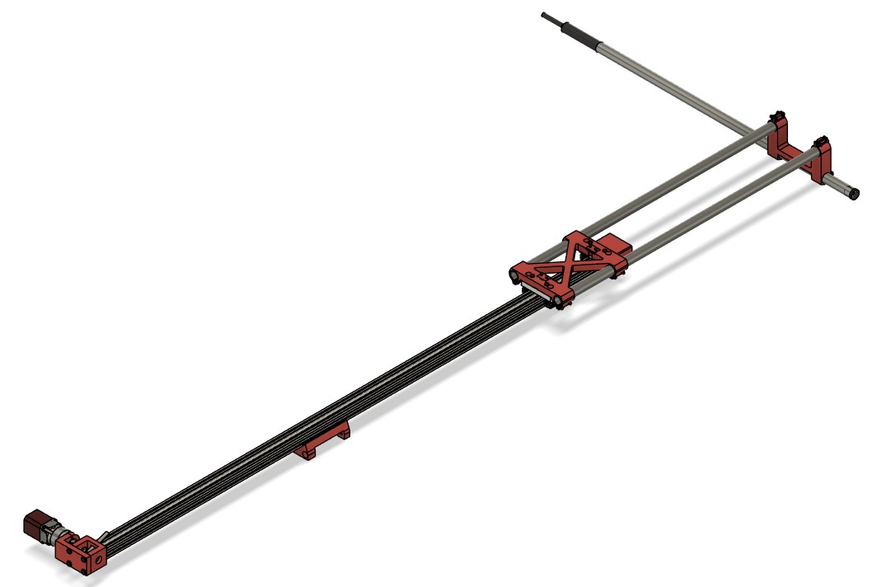
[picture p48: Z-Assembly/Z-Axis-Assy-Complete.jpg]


The core element is a v-slot20x40 beam of 1400mm long, with M5 threading on both ends. 
The other main parts are the:
Motor-Kant, 
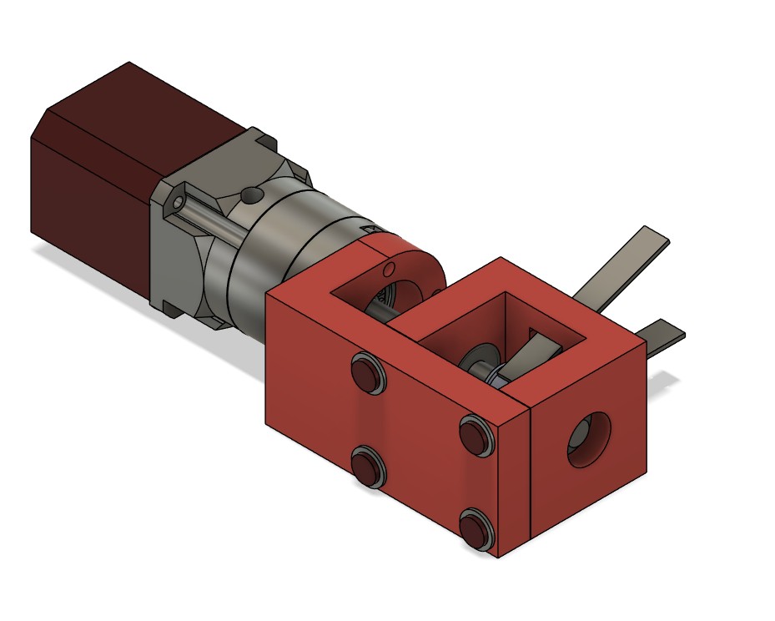
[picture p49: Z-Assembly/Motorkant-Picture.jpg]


the Spanner-Kant, 
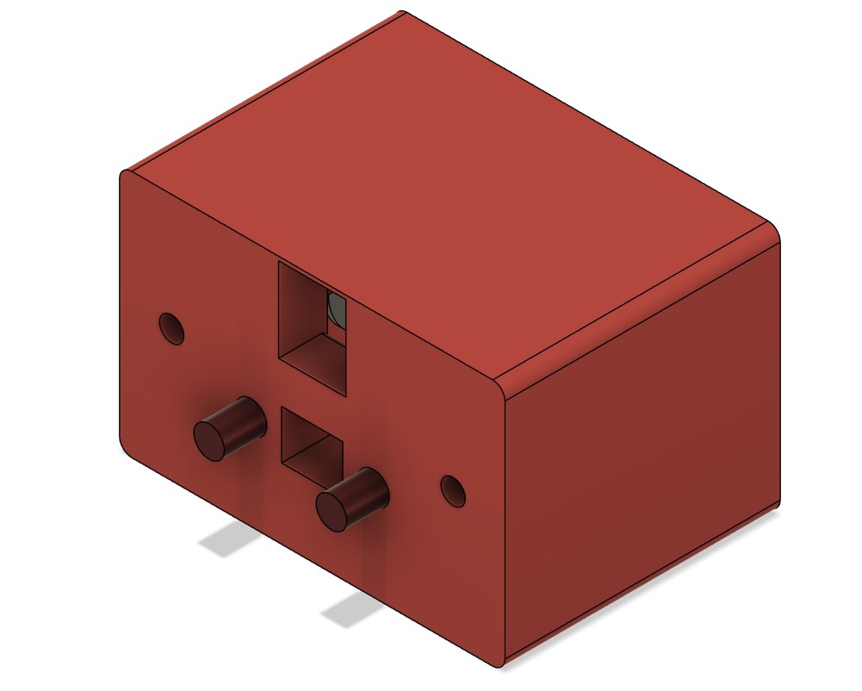
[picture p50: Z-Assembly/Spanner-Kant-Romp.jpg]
 
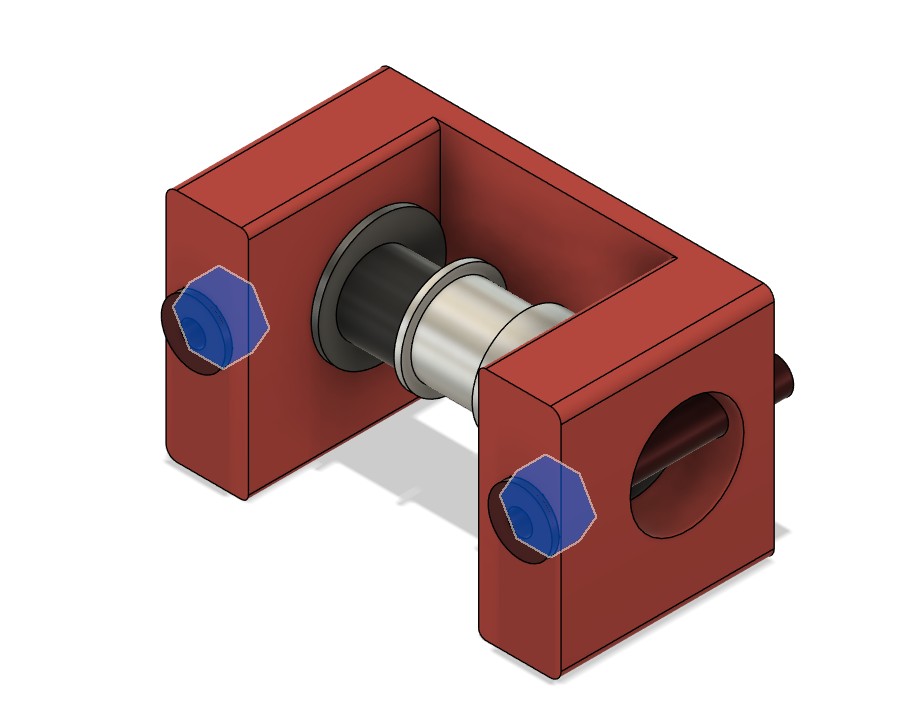
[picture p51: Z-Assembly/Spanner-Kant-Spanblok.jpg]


The Gantry-Montage 
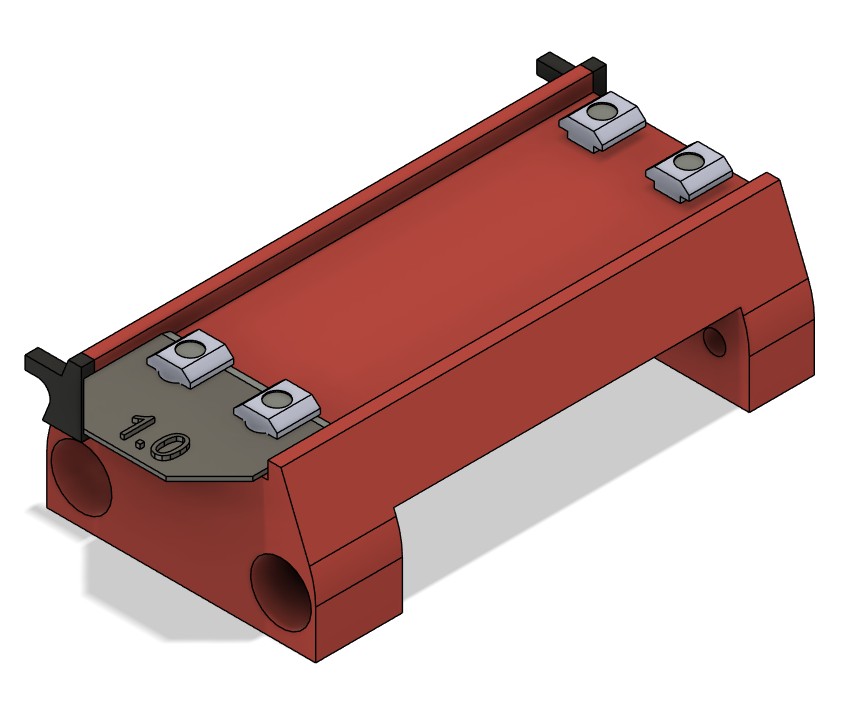
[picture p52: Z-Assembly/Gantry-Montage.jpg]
 

and the X-Gantry-assy, including a shim plate, see explanation below.

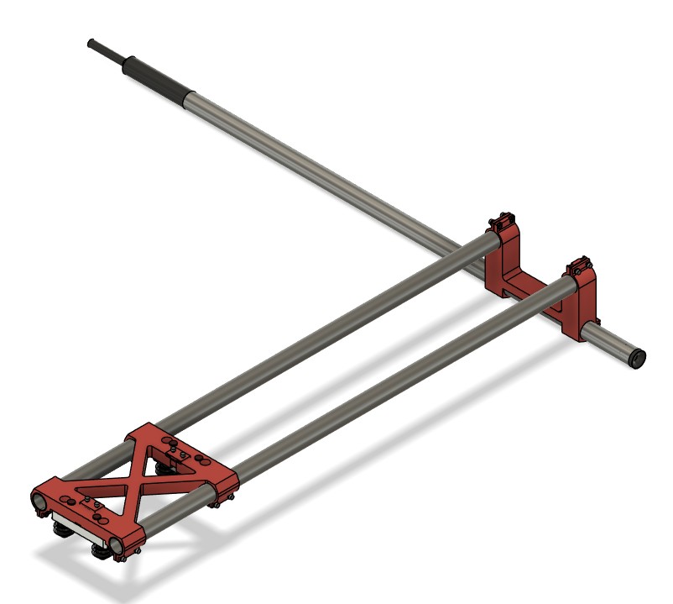
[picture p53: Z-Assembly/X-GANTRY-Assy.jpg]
 

The motor and reduction gear are displayed here, but are covered in the Motors section BoM.
For the toothed belt a GT@-9mm open end belt is used, with appropriate toothed pulleys to drive the gantry up and down.

Included in this section is an Excel with my design decisions, and a BoM . Also included is a F-360 file with the whole assembly, and also one in STEP format.

When complete and mounted on the Gantry of the Arm, for the vertical squaring a shim will probably be needed. So shim is one of the 3D printable parts, with the thickness that needs to be defined during squaring. Its thickness is quite sensitive, 0.1mm makes already a difference.

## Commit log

2026-04-06 Delete STOOL/DUT-STOOL V1.0.step
    wrong file
    [DUT-STOOL V1.0.step]
2026-05-03 Update README.md
    Belt info corrected
2026-05-03 Model completed, BOM completed
    [HALS-Rotating-DriveHTD3M-270t-20t-1068mm.f3d, HALS-Rotating-DriveHTD3M-270t-20t-1068mm.step, RotatingDrive.xlsx]
2026-05-03 First upload of CABLING data
    [CSC-Cabling-Sizing-Config.xlsx, Cable-Harness-Assembly.f3z, Microswitch.f3d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]
2026-08-31 Delete MOTION directory
    replaced by MOTION&CABLING
    [17HS19-2004S2.STEP, 17HS19-2504S.STEP, 17HS24-0644S.STEP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]
2026-09-21 Add files via upload
    Uploaded files, apparently the previous upload has failed.
    [CSC-Cabling-Sizing-Config.xlsx]
2026-10-04 Add files via upload
    DUT STool 2.0, a much tighter fit!
    [DUT-STOOL V2.0x.f3d]
2026-10-20 Add files via upload
    Explanation of the fit of rotating drive chassis on the tripod
2026-10-20 Update README.md
    Fit of rotatingdrive chassis on main component of tripod is shown
2026-11-06 Add files via upload
    Stool V3.0
    The cable gutter is increased to 12mm in width and depth to accomodate thicker cables, like a mains power and an balanced XLR cable. Also small update of the Triangle part to meet the 12mm width of t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
